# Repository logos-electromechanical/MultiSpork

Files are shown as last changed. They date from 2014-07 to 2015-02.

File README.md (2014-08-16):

MultiSpork
==========

A wireless analog/digital multitool &amp; data recorder.

When I'm working on a mobile robotics projects, I often wish I could attach my scope, logic analyzer, or signal generator to some aspect of the 'bot without tethering it to the bench. IOW, what I need is some kind of widget that does the data acquisition on the 'bot and sends it back to a screen. Ideally, it would also have plenty of range, easy configuration, a nice interface (Saleae is my model for how this should be). 

Maxim just released a chip, the MAX 11300, that incorporates a good chunk of what's required for this. It gives you twenty channels, each of which can by ADC, DAC, or GPIO, and communicates over a fast SPI bus. Add an Atmel SAM processor (I already have the dev tools, so this is an easy decision) and a wifi module, and we're in business. Cheap wifi-only Android tablets can be had for as little as $50, so Android is the obvious choice for a host OS. 

See the MultiSpork/documentation/MultiSporkSystemDescription.md for more info. This will go into the wiki when it's complete.

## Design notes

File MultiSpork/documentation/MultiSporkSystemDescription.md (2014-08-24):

MultiSpork -- A Wireless Analog/Digital Multitool
=================================================================

# Concept #

The MultiSpork is an analog and digital multitool. It has the following properties:

* It has twenty channels can function as a 12-bit ADC, a 12-bit 25 mA DAC, or a GPIO line. 
* Interfaces wirelessly with a tablet or other display device for user input and data presentation. 
* Robust
* Able to store data locally on an SD card
* Able to operate without continuous network connection
* Initial set-up is easy/straightforward
* Both firmware and app incorporate plug-in frameworks to allow easy 3rd party upgrades.
* Replicates behavior of a mixed-signal oscilloscope
* Replicates behavior of a logic analyzer
* Replicates behavior of a signal generator

Features listed as (OPTIONAL) are ones that I haven't decided I'm definitely going to implement immediately, but that would be nice in the future. 

----------

# Hardware #

## General Hardware Requirements ##
The hardware must conform to the following requirements:

* It must be electrically robust against common insults, especially over-voltage, over-current conditions, and the sort of ESD likely to be encountered in field conditions.
* It must be robust against plugging connectors in backwards. Therefore, all connectors must be either keyed, tolerant of connector reversal, or both. 
* The hardware must be amenable to expansion
* It must be mechanically robust, particularly the connectors. 

## Subsystems ##

### Analog Front End/Digitizer ###

The ADC/DAC/GPIO services are provided by the MAX11300. This chip provides twenty lines, each of which may be individually programmed to act as an ADC, a DAC, or a GPIO. All ADC and DAC channels are 12-bit, and share a total of 400 ksps. 

Voltage ranges are as follows:

|**Function** 	| **Voltage Range** |
|---|---|
|ADC			| 	0-10V			|
|				|	-5V to 5V		|
|				|	-10V-0			|
|				|	0-2.5V			|
|---------------|-------------------|
|DAC			| 	0-10V			|
|				|	-5V to 5V		|
|				|	-10V-0			|
|---------------|-------------------|
|GPI			|	0-5V input		|
|				|	0-2.5V threshold|
|				|	(programmable)	|
|---------------|-------------------|
|GPO			|	0-10V (programmable)|
|---------------|-------------------|

#### Voltage Reference ####

Only the internal voltage reference(s) are available.

#### Temperature ####

Both external temperature sensors lines are hooked up to MMBT3904 transistors. This circuit is cribbed directly from the MAX11300 evaluation board. 

#### Host Interface ####

The SPI lines are hooked directly to the MCU, as are the CNVT and INT lines.

#### I/O Protection Circuit ####

Each of the channels has the following circuit:

The series diodes restrict the voltage at MAX11300 input pin to between -10V and +10V. The PTC fuse limits the current to 25 mA in order to prevent damage. 

#### I/O Connector ####

The analog I/O connector is an FCI 76385-316LF soldered to the edge of the board. This is a 2x16 0.1" pitch pin header. This reduces the height of the assembled board and increases mechanical strength. While this is a keyed connector, it can accept non-keyed IDC plugs. Therefore, the pinout is symmetrical, so that reversing the connector will not connect any power or ground rail to any I/O line or to any other power or ground rail.

Pinout is as follows:

| **Pin** 	| **Function** 		|
|---|---|
| 1			| Analog Ground		|
| 2			| +3V3				|
| 3			| Digital Ground	|
| 4			| +5V				|
| 5			| -10V				|
| 6			| +10V				|
| 7			| PORT 00			|
| 8			| PORT 01			|
| 9			| PORT 02			|
| 10		| PORT 03			|
| 11		| PORT 04			|
| 12		| PORT 05			|
| 13		| PORT 06			|
| 14		| PORT 07			|
| 15		| PORT 08			|
| 16		| PORT 09			|
| 17		| PORT 10			|
| 18		| PORT 11			|
| 19		| PORT 12			|
| 20		| PORT 13			|
| 21		| PORT 14			|
| 22		| PORT 15			|
| 23		| PORT 16			|
| 24		| PORT 17			|
| 25		| PORT 18			|
| 26		| PORT 19			|
| 27		| +10V				|
| 28		| -10V				|
| 29		| +5V				|
| 30		| Digital Ground	|
| 31		| +3V3				|
| 32		| Analog Ground		|

### MCU ###

The microcontroller is an Atmel SAM3S4A. This chip comes in a QFN 48 package and sports 256K of flash and 48K of SRAM. Clock speed is 64 MHz and maximum SPI speed is 45 MHz. 

Programming is accomplished either via USB or the JTAG interface. 

A 20 MHz crystal regulates the on-chip crystal oscillator

Microcontroller circuitry follows the datasheet to the extent required & practical.

The SPI bus provides the only means of communication between the major subsystems.

The MCU will have at least 1 MByte of external SRAM in order to support a sufficiently deep buffer to tolerate excessive waits from the SD Card.

#### Accessory connector ####

The accessory connector exposes the serial communication interfaces of the MCU in order to provide a place for adding additional hardware. It is a 2x5 0.1" pitch pin header. It is not populated by default. 

Pinout is as follows:

| **Pin** 	| **Function** 		|
|---|---|
| 1			| MOSI (SPI Bus)	|
| 2			| +3V3				|
| 3			| SCLK (SPI Bus)	|
| 4			| RXD0 (UART0)		|
| 5			| MISO (SPI Bus)	|
| 6			| TXD0 (UART0)		|
| 7			| ACC_CS (SPI Bus)	|
| 8			| SCL (I2C Bus)		|
| 9			| SDA (I2C Bus)		|
| 10		| Digital Ground	|

### WiFi ###

Wireless communication is provided by a Texas Instruments CC3100. This 2.4 GHz WiFi SoC provides all network services required for the MultiSpork to communicate with its host tablet. 

The CC3100 is configured to act as an access point. This eliminates the need for the user to execute any wired configuration step prior to using the MultiSpork. Access point configuration options will naturally be available from the tablet app. 

CC3100 wiring follows the dictates of the datasheet. 

### USB ###

USB is a native peripheral of the microcontroller. The USB port is protected against ESD and electrical insults by series resistors.

USB power is used to charge the battery.

### SD Card ###

A micro-SD card slot provides non-volatile data storage when the Multispork is directed to log incoming data. It also provides storage for outgoing waveforms and (possibly) scripts to run. 

### Idiot Lights ###

The MultiSpork shall have the following idiot lights. Features listed in *italics* have not yet been implemented as of commit 872e8fda3353304001933b7b57375441d28ed381.

* Charge, red LED
* *Power, green LED*
* *State, RGB LED*

### Power ###

#### Switch ####

The power switch controls the enable lines of all of the voltage regulators. In the off position, it puts them all to sleep.  

#### Battery ####

Main power for the device is provided by a single LiPo cell (2.7-4.2V) with a 2mm JST connector. This battery is intended to be permanently installed, but can be removed and upgraded if required for a specific application.

The battery is charged by an MCP73831 linear charge controller set to 500 mA of charge current. 

#### 3.3V Rail ####

The 3.3V rail powers the MCU, the WiFi chip, and the digital interface of the MAX11300. It therefore has the highest power demand of any of the power rails.

This rail is driven by an LT3580 regulator configured to run in SEPIC mode. The components are sized to provide a current output of 800 mA.  

#### 5V Rail ####

The 5V rail powers the core of the MAX11300. Like the 3.3V rail, it is driven by an LT3580 regulator running in SEPIC mode. The current output is 400 mA. 

#### +10V Rail ####

The +10V provides the high voltage positive rail for the MAX11300. It is driven an LT3580 configured as a boost regulator. Current output is 350 mA. 

#### -10V Rail ####

The -10V provides the high voltage negative rail for the MAX11300. It is driven by an LT3580 configured as an inverting regulator. Current output is 350 mA. 

#### Analog Ground ####

The analog ground plane is connected to the digital ground plane through a small resistor. 

## Mechanical ##

### PCB ###

The production version of the MultiSpork will fit within a Dangerous Prototype DP8049 Sick of Beige footprint. 

The PCB will be a four-layer design, 0.062" finished thickness. 

### Case ###

The case will be a milled Delrin case with an acrylic lid. It will have space for a battery and associated retention features. The case shall also provide a mechanism to operate the reset button and the power switch. It shall also provide visibility for the charge and power LEDs. 

## Future Hardware Features ##

This is a list of things that I have thought of that would be nice to have but are probably not worth the candle, at least at the time.

* GPS for accurate time and location tagging (see, for example, the SE4150L -- $3/ea in singles). This is significantly more interesting than just an RTC.
* External RAM for larger on-board buffer

----------

# Firmware #

The firmware configures the MAX11300, and exchanges data with the MAX11300, the WiFi, and the SD card. It has the following functions:

* Acquire data from the ADC and GPI at full speed (400 ksps)
* Pipe data to the DAC and GPO at full speed
* Provide access to all major MAX11300 and CC3100 configuration options
* Log data to SD card
* Read arbitrary waveforms from SD card
* Transmit data over WiFi to tablet
* Generate standard analog waveforms (sine, square, triangle, white noise, etc)
* Generate standard digital waveforms (PWM, PCM, etc)
* Capture data from ADC/GPI based on trigger conditions (level and edge triggers)
* Transmit data over DAC/GPO based on trigger conditions
* (OPTIONAL) Apply arbitrary polynomial transfer functions to incoming data
* (OPTIONAL) Apply mathematical functions (add, subtract, multiply, trig) to incoming data
* (OPTIONAL) Pipe filtered data to arbitrary DAC channel
* (OPTIONAL) Read configuration options from SD Card
* (OPTIONAL) Read and write data from accessories on the SPI and I2C busses
* (OPTIONAL) Run arbitrary LUA scripts on incoming/outgoing data

## Configuration ##

The general intention is that the configuration options in the firmware are thin wrappers around the MAX11300 and CC3100 configuration registers. 

## Data Flow ##

The major system blocks are as follows:

* **MAX11300** -- Primary physical interface, both in and out
* **MCU SPI** -- The communications bus with all peripherals save the USB
* **MCU buffers** -- Internal RAM buffers used for input and output 
* **MCU filters** -- Internal filter programs
* **MCU signal generator** -- Algorithmic signal generation
* **SD Card** -- Local SD card for storing data
* **CC3100** -- WiFi connection to host app
* **USB** -- USB connection to host app
* **Host App** -- Host application running on a tablet or other computer

### MAX11300 ###

The MAX11300 block communicates via the MCU SPI block. It takes in commands, configuration, and output data. It puts out input data from its analog and digital inputs. 

### MCU SPI ###

The SPI is the communications bus that connects the MAC11300, the MCU (and all its internal blocks), the SD card, and the CC3100. It may carry any of the data types that these blocks transmit or receive. 

### MCU buffers ###

The MCU buffers incoming and outgoing data from and to the MAX11300 that is either going to or received from other blocks over the SPI. Each active channel has its own buffer, which will be either read or write depending on what function is currently configured on that channel. The WiFi, the USB, and the SD card each have a read and a write buffer.

### MCU filters ###

The MCU can run filters (decimation, low pass, various multi-input math functions etc) against data that is in any buffer. The output is written to another buffer. 

### MCU signal generator ###

The signal generator fills an output buffer with a specified function. Here is a list of functions to be implemented in the first iteration:

* sine wave
* square wave
* triangle wave
* sawtooth wave
* PWM

### SD Card ###

The SD card is a data store that the MCU can either write to or read from via SPI bus.

Output data files will be stored as plain text CSV files in the format <channel>,<time>,<value>,<units>. In the case of raw values, the value of the <units> field shall be 'raw'. Any other value shall be set by the translating filter.

Input data files shall be in .wav format. The name and details of the .wav file are set by the 

### CC3100 ###

The CC3100 provides the WiFi link to the host app. It sends and receives data and commands from the MCU via SPI and communicates with the host app via WiFi. 

### USB ###

The USB performs the same functions as the WiFi when the USB is connected to a host. 

### Host App ###

The host app is the ultimate data sink and source in the system. It provides the following types of data to the device:

* Commands (i.e. state changes, state details)
* Configuration (i.e. trigger settings, channel settings)
* .wav files for data output
* (OPTIONAL) Commands, config, and outgoing data for things attached to the accessory connector.

The host app receives the following types of data from the device:

* Streaming input data from the MAX11300
* Status from various parts of the device

## States ##

### Setup ###

This is the state that the MultiSpork enters upon power-up or reset. In this state, it performs the following tasks before transitioning to either Standby or Logging mode (depending on configuration).

1. Configures CC3100 per one of the following profiles (listed in priority order):
	1. (OPTIONAL) WiFiConf.txt, stored on the SD Card
	2. The wifi configuration stored in the EEPROM of the MCU
	3. The default wifi configuration  
2. Configure the MAX11300 per one of the following configurations (listed in priority order):
	1. (OPTIONAL) IOConf.txt, stored on the SD Card
	2. The I/O configuration stored in the EEPROM of the MCU
	3. The default I/O configuration  
4. Chooses mode to enter based on either EEPROM or (OPTIONAL)SD Card configuration.
5. Gets current data/time from host device.

### Standby ###

This is the default waiting state. The primary activity in this state is executing configuration commands from the host app. The device will depart this state for pre-trigger, running capture, or logging based on input from either the host app or from a command file on the SD card. 

The MCU can generate or output a signal through the MAX11300 in this mode and any other except Setup. 

### Pre-Trigger ###

During the pre-trigger state, the MCU commands the MAX11300 to sample the target channel(s) and saves the buffer such that when the trigger condition occurs, the app can display data from both before and after the trigger condition. 

Trigger conditions can come from any of the following sources:

* Analog input
* Digital input
* Analog output
* Digital output
* Internal timebase

Any of the following conditions can be used to trigger a capture

* Level trigger
* Edge trigger
* Periodic trigger
* Free run

Once the trigger condition is satisfied, the firmware transitions to the next state (either Triggered Capture, Running Capture, or Logging) as dictated by the received commands. 

### Triggered Capture ###

During a triggered capture, the device captures and streams data until it reaches the end of the specified capture window. It then either returns to the pre-trigger state or to standby, depending on whether the triggering is set to be continuous or one-shot.

### Running Capture ###

During a running capture, the device captures and streams data to the host app continuously, either via USB or WiFi. Starting and stopping 

### Logging ###

Logging works like a running capture except that the target is the SD card rather than USB or WiFi. Depending on settings, the MCU filters may decimate or otherwise process the incoming data before writing it out. 

It shall be possible to configure this state such that the logging proceeds for a limited time period and then transitions back to pre-triggered or standby. 

----------

# Host App

The host app will be designed to present the acquired data in a format that can be readily viewed and manipulated by the user. 

The host app shall be written in Kivy or similar cross-platform framework that allows them to run on not only Android tablets but also on Windows, Linux, and Mac. 

The host app interface will follow the wireframes at https://logoselectromechanical.mybalsamiq.com/projects/multispork/

----------

# Communications

The maximum data rate from the MAX11300 is 4.8 Mbps. This provides plenty of SPI bus headroom to stream to the host app and record simultaneously, since its maximum speed is 20 Mbps, as long as there's a minimal amount of framing data. This means that the outgoing data needs to be packed up such that a single set of framing data covers a substantial period of communications.

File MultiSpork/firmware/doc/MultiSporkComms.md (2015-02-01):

# Communications #

## Hardware Components ##

### Host ###

The host is the user interface device. Typically, this will be an app running on an Android tablet, but it may be any computer running the appropriate software. 

Typically, all transactions with the exception of raising interrupts are initiated by the host. 

### Device ###

The device is the operational head of the system. The Multispork is the only device at this time. 

# Transactions #

Each transaction starts with the initiating party (always the host except for raising interrupts) send a request. The other party then sends one or more messages in response. 

Communications is serialized with the [Cap'n Proto](https://capnproto.org/) package. All message descriptions use the terminology of that package. 

## Parameters ##

Parameters are the configuration values used to tell the device how to operate. The value and identity of each parameter are defined with the type `ParamStruct`.

### Messages ###

#### `ParamStruct` ####

This structure contains all the information required for a particular parameter.

- `name` This is the text name of the parameter. This is not necessarily a unique value and exists mostly for readability.
- `guid` This is a 64-bit globally unique ID number. It must not overlap with other guids for other message types. A single guid may exist for multiple channels. 
- `channel` This is the channel to which this particular value applies. A single guid may cover multiple channels. If the parameter covers all channels, this value should be 255.
- `value` This is the value of the parameter. Any unitary type from Cap'n Proto can be used here. `Void` is used signal a request.

#### `ParamErr` ####

This is an enumerated type that is used to transmit an error if a parameter transaction fails for some reason. The values it can assume are as follows:

- `none` No error
- `invalidParamName` Invalid parameter name. Returned if the guid does not match the name.
- `invalidParamGUID` Invalid guid. Returned if the guid does not exist.
- `invalidParamValue` Invalid parameter value. Returned if the parameter is out of range. 
- `invalidParamChannel` Invalid parameter channel. Returned if the parameter has an incorrect channel.
- `accessDenied` Not currently used
- `paramSetFail` Parameter set failed. Returned if the device is unable to set the parameter value for a reason no previously listed. 
- `invalidParamType` Invalid parameter type. Returned if the parameter type sent to the device does not match the internal type. 

### Getting a Parameter ###

In order to get the current value of a given parameter, the host sends a `ParamStruct` with the name, UID, and channel of the desired parameter value of `request`, which is of type `Void`. 

The device responds either with the requested `ParamStruct` and a `ParamErr`. `ParamErr` is an enumerated type containing a variety of possible error types.

If the parameter exists, the device sends the host a `ParamStruct` for that parameter including the value.

If the parameter does not exist, the device responds with a `ParamErr` with an appropriate value. 

### Setting a Parameter ###

In order to set a parameter, the host sends the device a `ParamStruct`. The device responds with a `ParamErr`.

### Getting a List of Parameters ###

In order to get a list of parameter, the host sends a `List(ParamStruct)` containing a single empty parameter. The device responds with a `List(ParamStruct)` containing all device parameters. 

## Interrupts ##

The device sometimes needs to interrupt the host, for example, when a buffer is full and ready for reading.

Upon receiving an interrupt, the host takes whatever actions are necessary to deal with the interrupts, and then sends the `IntStruct` back to clear the interrupt. 

### Messages 

#### `IntStruct` ####

- `name` The natural language name of the interrupt.
- `guid` The globally unique 64 bit ID of the interrupt.
- `channel` The channel to which the interrupt applies. An interrupt that applies to all channels or no channel in particular fills this with the value 255.

## Buffers ##

Buffers are where the data being read into the device (via GPI or ADC) or out of the device (via GPO or DAC) are stored. Typically, buffers come in pairs so one or the other can be manipulated by the host while the other is being read from or written to by the device. 

### Messages 

#### `BufStruct`

- `ID` is a `BufID` struct containing all of the data about the buffer's identity. Its members are as follows:
	- `channels` contains a list of channel numbers addressed by this buffer. It is a `List(UInt8)`.
	- `bufNum` is the buffer number, which makes it straightforward to keep track of different buffers for the same channel list. It is a `UInt8`.
	- `rate` is the sample rate of the buffer. It is a `Float32`.
	- `startTime` is the start time of the buffer. It is a `UInt64`.
	- `size` is the size of the buffer, in samples. It is a `UInt32`. The size of the buffer in bits is equal to `size` times `resolution`.
	- `contentSize` is the number of samples currently in the buffer.
	- `resolution` is the size of each sample, in bits. It is a `UInt8`, and for the MultiSpork will be either equal to 12 (for an ADC or DAC buffer) or 1 (for a GPIO buffer).
	- `direction` is the direction that the buffer will be written. It is a `Bool` and is true for an input buffer and false for an output buffer.
	- `active` is a `Bool` that is true if the buffer is being actively read to or written from by the device and is false otherwise. 
- `contents` is a `Data` blob containing the contents of the buffer. The samples are packed together with no padding, and contains the samples from each channel called out in the channel list in a maximum density packing.

#### `BufErr` ####

This is an enumerated type with all the possible buffer errors.

- `none` No error
- `bufDoesNotExist` There is no buffer with the given channel list.
- `bufEmpty` There are no samples in the buffer. 
- `bufOverflow` Either `contentSize` is larger than `

### Getting a Buffer ###

In order to get a buffer, the host sends a `BufStruct` that is empty except for the `channels` and the `bufNum`. If that channel list corresponds to a buffer on the device, the device responds with a fully populated `BufStruct`. Otherwise, it will return a `BufErr` with an appropriate value.

### Writing a Buffer ###

In order to write a buffer, the host sends a fully populated `BufStruct`. If that buffer corresponds to a buffer on the device, the device responds with a `BufErr` with the value `none`. Otherwise, it will return an appropriate error.

### Getting a List of Buffers ###

To get a list of all valid buffers, the host transmits a `List(BufID)` containing a single empty instance of `BufID`. The device responds with a `List(BufID)` containing all buffers currently in use. 

# Multispork Configuration #

This is a list specifically of the configuration of the MultiSpork. Other devices will likely have different parameters.

## Parameters ##

### Network ###

**Name** | **GUID** | **Type** | **Permitted Values** | **Default** | **Function** | 
---------|----------|----------|----------------------|-------------|--------------|
Device Name | | String | Any string that is permissible as an internet host name | multispork\<serial number\> | This is a name to allow the user to identify different devices from a single host. This is also the network SSID in host mode |
Device IP Address | | UInt32 | Any valid IP address | 10.10.10.10 | This is the IP address of the device. In client mode, this will be populated via DHCP; otherwise, it is populated from the last value stored in NVM |
WPA2 Key | | String | Any string | none | This is the password used for logging in to the device by the host. If the device is not in host mode, it will use this password to log in to the target network. |
Target SSID | | String | Any valid SSID | none | This is the network the device attempts to log in to in client mode |
Host Mode | | Bool | | true | When true, the device functions as a WiFi access point. Otherwise, it attempts to log in to the network stored in Target SSID |

### Global I/O Configuration ###

These are the parameters that control all channels of a given type.

**Name** | **GUID** | **Type** |**Channels Affected** | **Permitted Values** | **Default** |  **Function** |  
---------|----------|----------|----------------------|----------------------|-------------|---------------|
Sample Averaging | | UInt8 | All ADC | 1, 2, 4, 8, 16, 32, 64, or 128 | 1 | Set the number of samples averaged for each analog input sample transmitted to the host. |
ADC rate | | UInt16 | All ADC | 200, 250, 333, or 400 | 200 | The base sampling rate in ksps. The delivered sampling rate is `ADC rate`/`Sample Averaging`. |

### Channel Configuration ###

Analog input channels may be 0-22, where 0-19 are the ADC channels, 20 is the internal temperature sensors, 21 and 22 are the external temperature sensors. Analog output and all GPIO channels may be 0-19.

**Name** | **GUID** | **Type** | **Channels** | **Permitted Values** | **Default** |  **Function** |  
---------|----------|----------|--------------|----------------------|-------------|---------------|
Channel Mode | | UInt8 | Any | 0-6, where 0 = off, 1 = single ended ADC, 2 = pseudo-differential ADC, 3 = differential ADC, 4 = DAC, 5 = GPI, 6 = GPO | 0 | Set the mode for the given channel |
Voltage Range || UInt 8 | Any | 0-7 | 0 | See voltage range table in MAX11300 datasheet for FUNCPRM_i[11:0] |
Digital Threshold | | UInt16 | Any channel currently in GPIO mode | 0-4095 | 4095 | Sets the threshold voltage for digital input with respect to the DAC threshhold described by the Voltage Range Parameter. In digital output mode, output voltage is 4x the digital input level |
Negative Differential Channel | | UInt8 | 0-19 | 0 | This is the negative side for the channel while in differential or pseudod-differential mode. The target channel must be turned off. |
Pseudo Differential Voltage | | UInt16 | Any channel currently targetted as the negative input of a pseudo-differential channel | 0-4095 | 0 | This is the negative terminal of a pseudo-differential channel. |
DAC Running | | Bool | Any channel configured as a DAC output | | false | When this is false, the value of the DAC channel will be equal to DAC voltage, given the value of Voltage Range. |
DAC Voltage | | UInt16 | Any channel configured as a DAC output and with DAC Running = false | 0-4095 | 0 | The voltage output of the given channel. |

### Trigger ###

**Name** | **GUID** | **Type** | **Permitted Values** | **Default** | **Function** | 
---------|----------|----------|----------------------|-------------|--------------|
Trigger Channel | | UInt8 | 0-19 | 0 (no trigger) | Defines which channel will be used as a trigger.|
Trigger Sweep | | UInt8 | 0-2 | 0 (auto) | Defines whether the triggering is auto (0), normal (1), or single (2). |
Trigger Armed | | Bool | | false | When the Trigger Sweep is in single sweep mode, the host sets this true to enable the next sweep |
Trigger Level | | Float32 | -10 to +10 | 0 | Trigger level in volts |
Trigger Type | | UInt8 | 0-2 | 0 | 0 = edge trigger, 1 = pulse trigger, 2 = slope trigger |
Trigger Slope | | UInt8 | 0-2 | 0 | 0 = rising, 1 = falling, 2 = either |

## Interrupts ##

**Name** | **GUID** | **Channel** | **Function** |
---------|----------|-------------|--------------|
Buffer Full | | The lowest channel number in the buffer just filled | Tells the host when the device has filled a buffer |
Trigger Tripped | | The channel of the trigger | Tells the host when the a trigger condition has fired |

## Buffers ##

The Multispork allocates a maximum of eight buffers -- two analog input buffers, two analog output buffers, two digital input buffers, and two digital output buffers. They are allocated dynamically in response to the configuration of the channels.

**Description** | **Buffer Num**  | **Channels** | **Function** |
----------------|-----------------|--------------|--------------|
Analog Input Buffer | 0 | All channels that are configured as analog inputs | Stores samples as they are read in via ADC |
Analog Input Buffer | 1 | All channels that are configured as analog inputs | Stores samples as they are read in via ADC | 
Analog Output Buffer | 0 | All channels that are configured as analog outputs and have the DAC Running parameter set to true. | Stores samples to be written out via DAC |
Analog Output Buffer | 1 | All channels that are configured as analog outputs and have the DAC Running parameter set to true. | Stores samples to be written out via DAC |
Digital Input Buffer | 0 | All channels that are configured as digital inputs | Stores digital inputs as they are read in |
Digital Input Buffer | 1 | All channels that are configured as digital inputs | Stores digital inputs as they are read in |
Digital Output Buffer | 0 | All channels that are configured as digital outputs | Stores digital outputs to be written out |
Digital Output Buffer | 1 | All channels that are configured as digital outputs | Stores digital outputs to be written out |

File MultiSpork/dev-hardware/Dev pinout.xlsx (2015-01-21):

 | MAX11300 |  | CC3100BOOST |  | Olimex
Connection | Pin | Function | Pin | Function | Pin | Function
1 | 6,12 | 3V3 | P1.1 | 3V3 | 3.3V
2 | 5,11 | GND | P2.1 | GND | GND
 |  |  | P3.2 | GND
3 |  |  | P3.1 | 5V | +5V_USB
4 | 4 | SCLK | P1.7 | SPI_CLK | PA14 | SPCK
5 | 3 | MISO | P2.7 | SPI_MISO | PA12 | MISO
6 | 2 | MOSI | P2.6 | SPI_MOSI | PA13 | MOSI
7 | 1 | CS |  |  | PB0 | GPIO
8 | 7 | INTB |  |  | PB2 | GPIO
9 | 10 | CNVTB |  |  | PB3 | GPIO
10 |  |  | P2.2 | IRQ | PA5 | GPIO
11 |  |  | P2.3 | SPI_CS | PA6 | GPIO
12 |  |  | P1.5 | nHIB | PA0 | GPIO
13 |  |  | P2.5 | nRESET | PA9 | GPIO
14 |  |  | P4.7 | NWP_LOG_TX | PA1 | GPIO
15 |  |  | P4.8 | WLAN_LOG_TX | PA3 | GPIO

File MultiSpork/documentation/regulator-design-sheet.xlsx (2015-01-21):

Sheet: +10V regulator (LT3580)
Part | LT3580
Vout | 10 | V | Output voltage
Iout(max) | 0.35 | A | Maximum current
Vin(bat) | 2.5 | V | Minimum battery voltage, after diode
Vin(USB) | 5 | V | USB bus voltage
Rfb | 105.4621849 | kΩ
DCbat | 0.79 |  | Duty cycle on minimum battery power
DCUSB | 0.55 |  | Duty cycle on USB power
fOSC | 1.914583333 | MHz
RT | 47.00 | kΩ
Tp | 522.31 | ns | Clock period, ns
DCmax | 0.89 |  | Max allowable duty cycle
Lmin(bat) | 0.64 | µH
Lmin(USB) | 0.45 | µH
Lmin(bat) | 3.56 | µH | Value to prevent subharmonics
Lmin(USB) | 0.56 | µH | Value to prevent subharmonics
Lmax(USB) | 14.16 | µH
Lmax(bat) | 9.54 | µH
Lfinal | 3.90 | µH | Selected value
IL-peak | 1.72 | A
Cin | 4.7 | µF
Cout | 20 | µF
Cseries | 2.20 | nF | Note that these are taken from the SEPIC converter in datasheet rather than calculated. They'll be done properly later.
Cparallel | 0.00 | pF
Rseries | 10.00 | kΩ
L p/n | SRR5018-3R9Y
L package | 2323 (5858 metric)

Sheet: 3.3V SEPIC regulator
Part | LT3580
Vout | 3.2 | V | Output voltage
Vd | 0.7 | V | Diode voltage drop
Iout(max) | 0.8 | A | Maximum current
Vin(bat) | 2.5 | V | Minimum battery voltage, after diode
Vin(USB) | 5 | V | USB bus voltage
Rfb | 23.82953181 | kΩ
DCbat | 0.64 |  | Duty cycle on minimum battery power
DCUSB | 0.45 |  | Duty cycle on USB power
fOSC | 1.914583333 | MHz
RT | 47.00 | kΩ
Tp | 522.31 | ns | Clock period, ns
DCmax | 0.89 |  | Max allowable duty cycle
Lmin(bat) | 1.78 | µH
Lmin(USB) | 0.91 | µH
Lmin(bat) | 1.01 | µH | Value to prevent subharmonics
Lmin(USB) | -0.44 | µH | Value to prevent subharmonics
Lmax(USB) | 11.72 | µH
Lmax(bat) | 7.73 | µH
L1 | 2.20 | µH | Selected value
L2 | 2.20 | µH | Selected value
IL1-peak(bat) | 1.56 | A
IL2-peak(bat) | 0.94 | A
IL1-peak(USB) | 1.63 | A
IL2-peak(USB) | 1.01 | A
Cin | 4.7 | µF
Cout | 20 | µF
Cseries | 1.00 | nF | Note that these are taken from the SEPIC converter in datasheet rather than calculated. They'll be done properly later.
Cparallel | 22.00 | pF
Rseries | 10.00 | kΩ
L1 p/n | 252012CDMCDS-2R2MC
L1 package | 1008 (2520 metric)
L2 p/n | 252012CDMCDS-2R2MC
L2 package | 1008 (2520 metric)

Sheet: +5V SEPIC regulator
Part | LT3580
Vout | 4.95 | V | Output voltage
Vd | 0.7 | V | Diode voltage drop
Iout(max) | 0.4 | A | Maximum current
Vin(bat) | 2.5 | V | Minimum battery voltage, after diode
Vin(USB) | 5 | V | USB bus voltage
Rfb | 44.8 | kΩ
DCbat | 0.72 |  | Duty cycle on minimum battery power
DCUSB | 0.55 |  | Duty cycle on USB power
fOSC | 1.914583333 | MHz
RT | 47.00 | kΩ
Tp | 522.31 | ns | Clock period, ns
DCmax | 0.89 |  | Max allowable duty cycle
Lmin(bat) | 0.50 | µH
Lmin(USB) | 0.64 | µH
Lmin(bat) | 2.05 | µH | Value to prevent subharmonics
Lmin(USB) | 0.53 | µH | Value to prevent subharmonics
Lmax(USB) | 14.11 | µH
Lmax(bat) | 8.71 | µH
L1 | 2.20 | µH | Selected value
L2 | 2.20 | µH | Selected value
IL1-peak(bat) | 1.27 | A
IL2-peak(bat) | 0.56 | A
IL1-peak(USB) | 1.38 | A
IL2-peak(USB) | 0.67 | A
Cin | 4.7 | µF
Cout | 20 | µF
Cseries | 1.00 | nF | Note that these are taken from the SEPIC converter in datasheet rather than calculated. They'll be done properly later.
Cparallel | 22.00 | pF
Rseries | 10.00 | kΩ
L1 p/n | 252012CDMCDS-2R2MC
L1 package | 1008 (2520 metric)
L2 p/n | 252012CDMCDS-2R2MC
L2 package | 1008 (2520 metric)

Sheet: -10V regulator
Part | LT3580
|Vout| | 10 | V | Output voltage
Iout(max) | 0.35 | A | Maximum current
Vin(bat) | 2.5 | V | Minimum battery voltage, after diode
Rfb | 120.1080432 | kΩ
DCbat | 0.83 |  | Duty cycle on minimum battery power
fOSC | 1.914583333 | MHz
RT | 47.00 | kΩ
Tp | 522.31 | ns | Clock period, ns
DCmax | 0.89 |  | Max allowable duty cycle
Lmin(bat) | 2.95 | µH
Lmin(bat) | 5.05 | µH | Value to prevent subharmonics
Lmax(bat) | 10.03 | µH
L1-final | 5.30 | µH | Selected value
L2-final | 5.60 | µH
IL1-peak | 1.97 | A
IL2-peak | 0.43 | A
Cin | 4.7 | µF
Cout | 20 | µF
Cseries | 2.20 | nF | Note that these are taken from the SEPIC converter in datasheet rather than calculated. They'll be done properly later.
Cparallel | NP | pF
Rseries | 10.00 | kΩ
L1 p/n | SRR5028-5R3Y
L1 package | 2323 (5858 metric)
L2 p/n | PM1008S-5R6M-RC
L2 package | 1008 (2520 metric)

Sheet: +10V regulator
Part | AD1614
Vout | 10 | V | Output voltage
Iout(max) | 0.35 | A | Maximum current
Vin(bat) | 2.5 | V | Minimum battery voltage, after diode
Vin(USB) | 5 | V | USB bus voltage
R1fb | 70.32128514 | kΩ
R2fb | 10 | kΩ
DCbat | 0.75 |  | Duty cycle on minimum battery power
DCUSB | 0.50 |  | Duty cycle on USB power
fOSC | 1.3 | MHz
Ton(bat) | 0.58 | µs
Ton(USB) | 0.38 | µs
Iripple(max) | 0.40 | A
Lmin(bat) | 3.61 | µH
Lmin(USB) | 4.81 | µH
Lfinal | 4.70 | µH | Selected value
IL-peak | 1.60 | A
Cin | 22 | µF
Cout | 22 | µF
Cseries | 1.00 | nF | Note that these are taken from the SEPIC converter in datasheet rather than calculated. They'll be done properly later.
Cparallel | 22.00 | pF
Rseries | 10.00 | kΩ

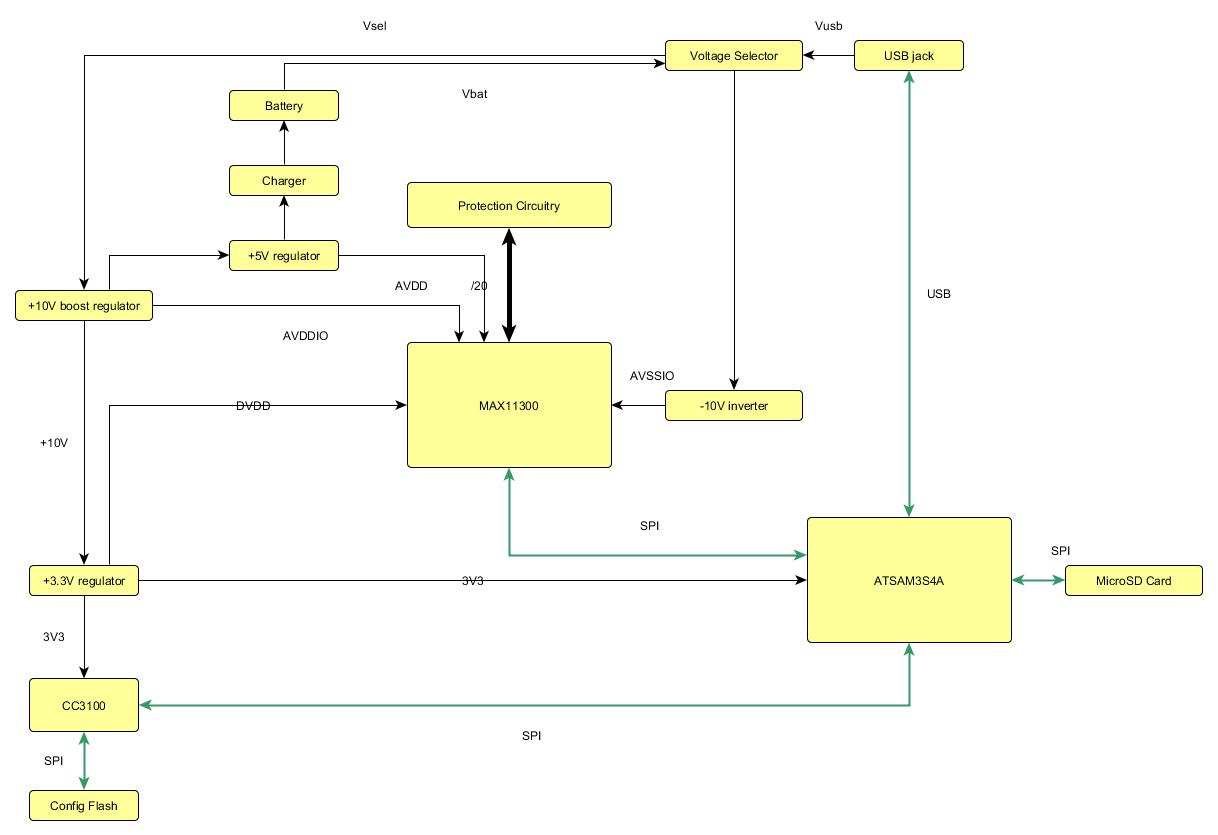
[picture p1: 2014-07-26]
MultiSpork/documentation/Hardware-block-diagram.jpg

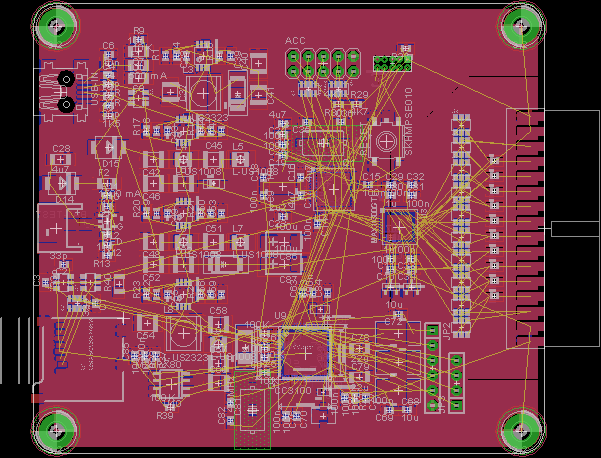
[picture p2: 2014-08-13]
MultiSpork/documentation/Multispork-placement-web.png

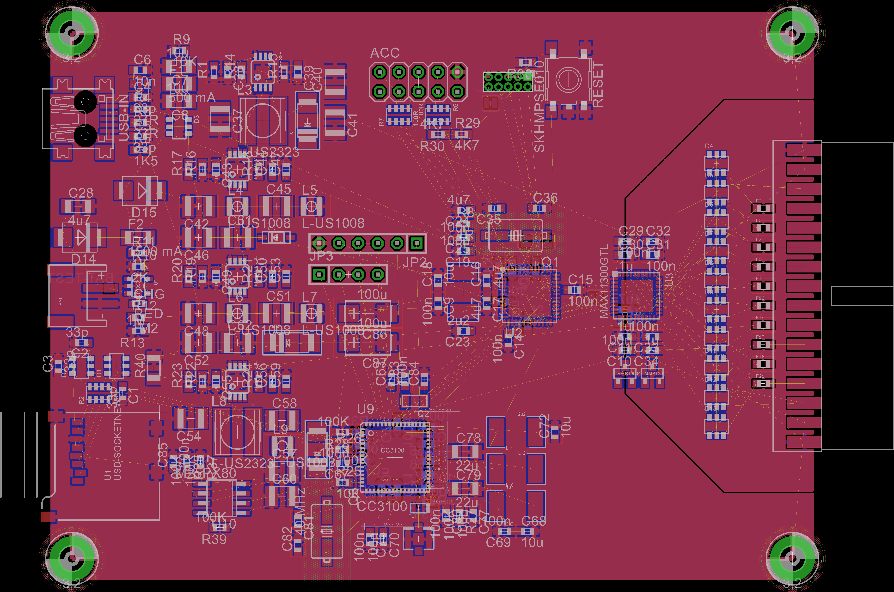
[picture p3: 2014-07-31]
MultiSpork/documentation/Multispork-placement.png

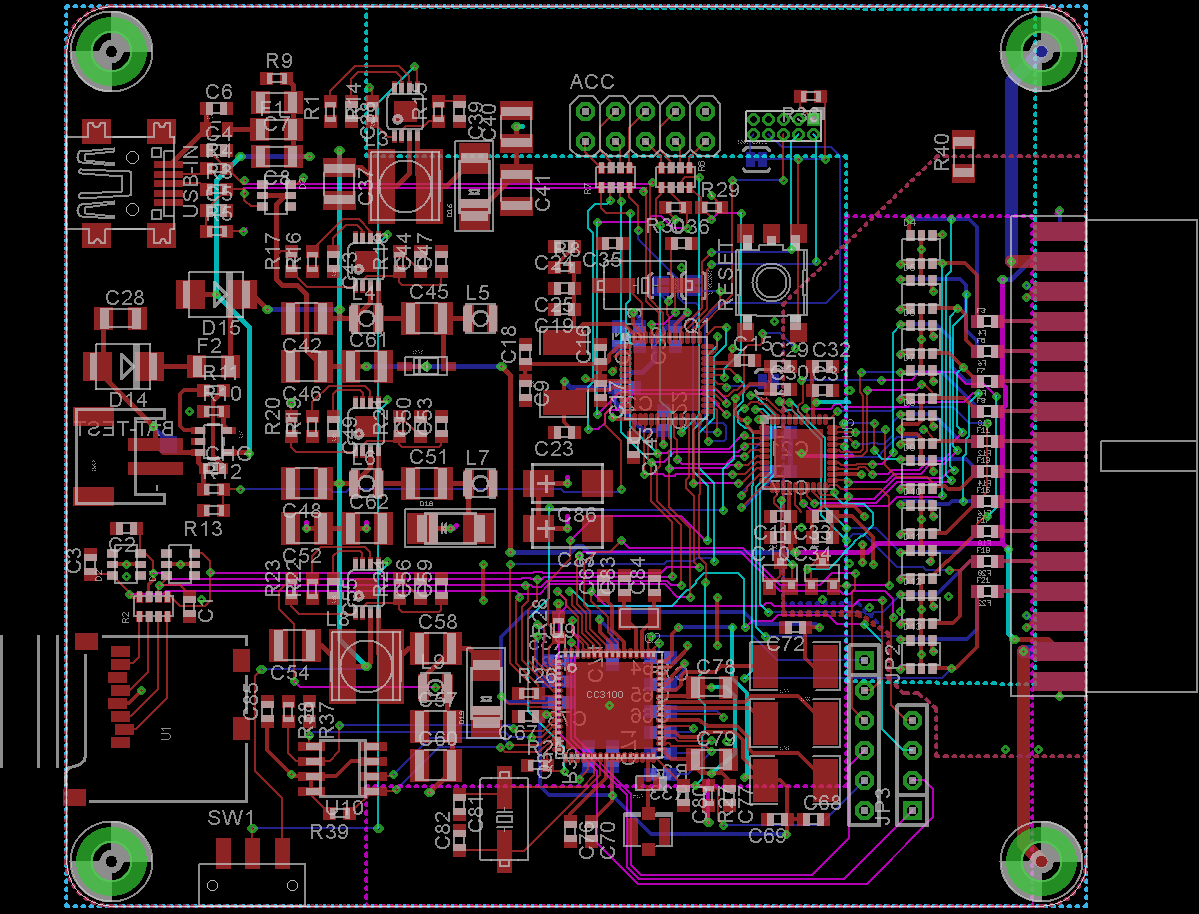
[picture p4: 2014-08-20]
MultiSpork/documentation/MultiSpork-v1-routed.png

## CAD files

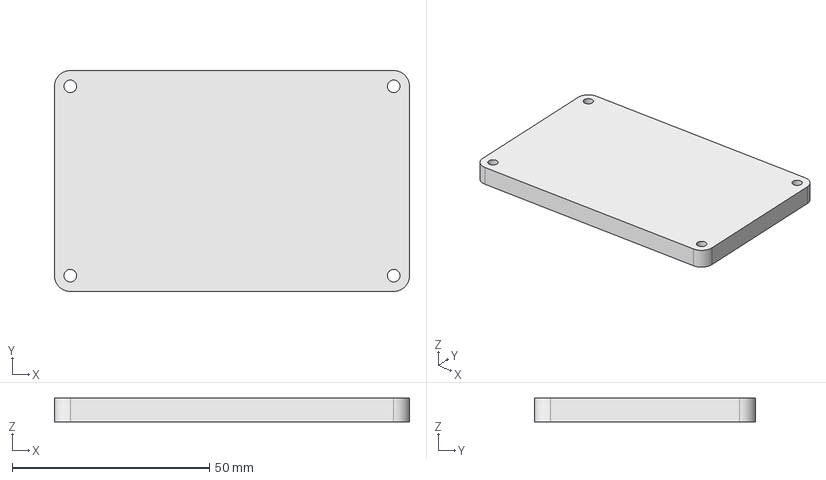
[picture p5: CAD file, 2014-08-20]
MultiSpork/case/mockup-top.FCStd
90.0 x 56.0 x 6.00 mm

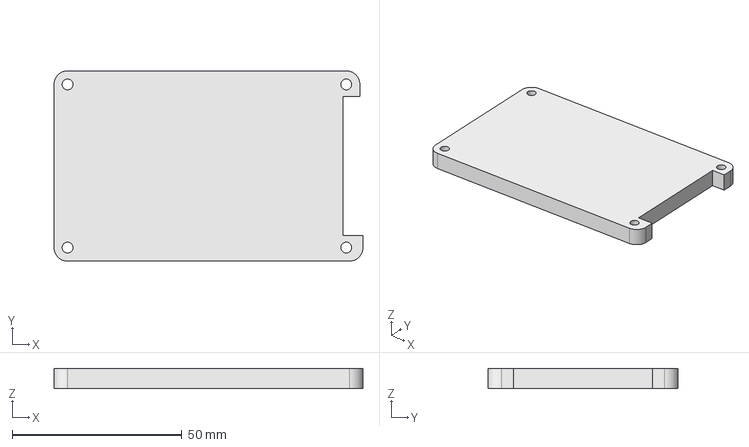
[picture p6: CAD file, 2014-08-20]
MultiSpork/case/mockup-center.FCStd
90.9 x 56.0 x 6.00 mm

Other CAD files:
MultiSpork/case/mockup-center.dxf
MultiSpork/case/mockup-top.dxf

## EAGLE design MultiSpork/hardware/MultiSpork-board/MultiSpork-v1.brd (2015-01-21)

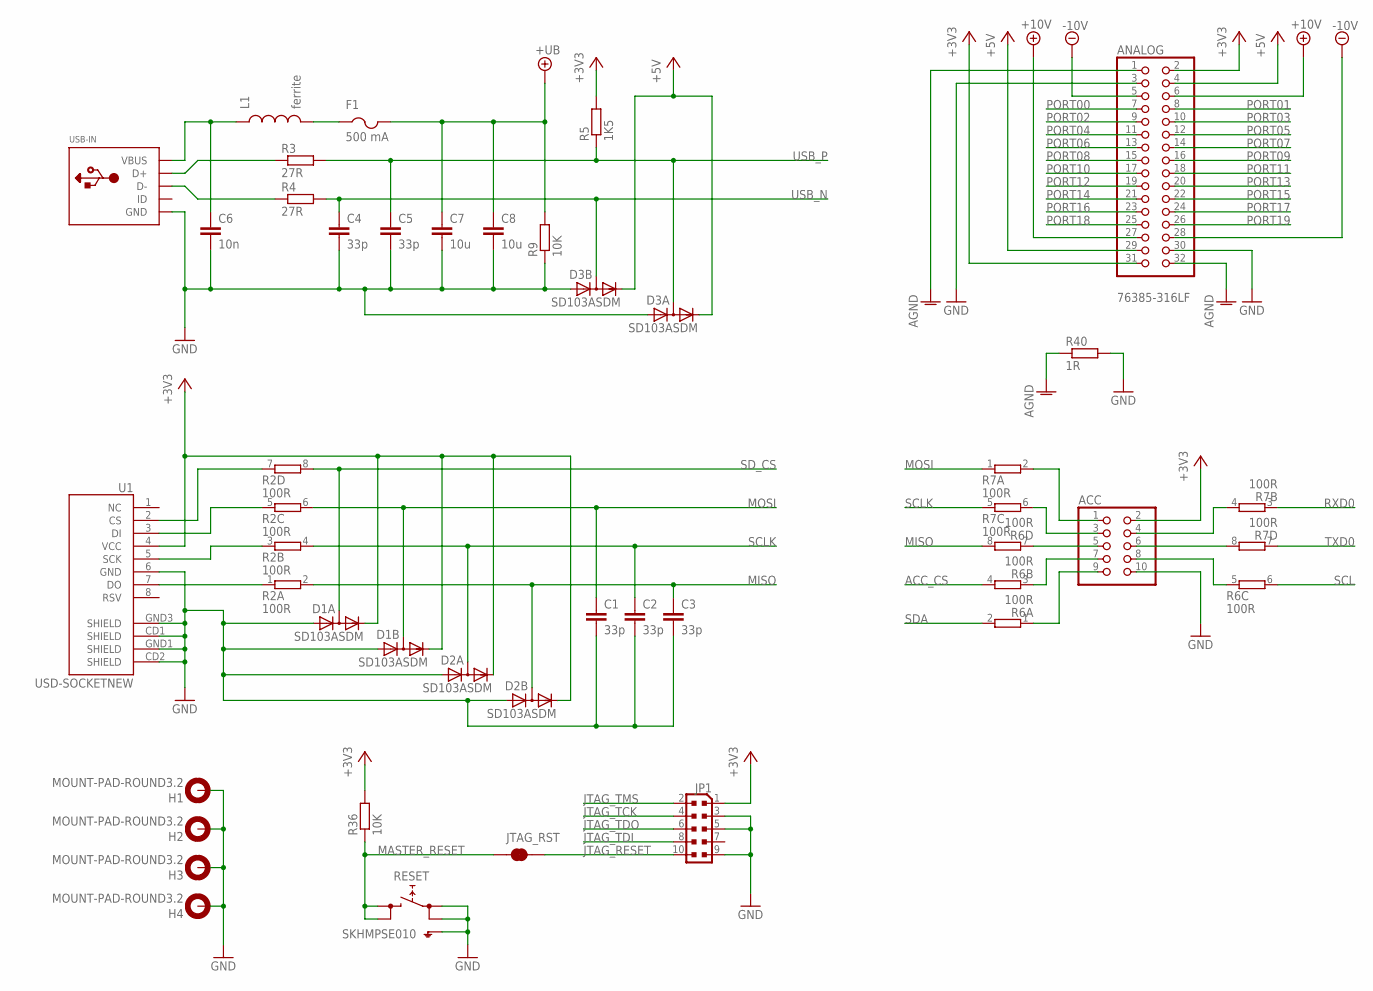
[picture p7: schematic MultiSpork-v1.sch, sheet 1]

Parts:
ACC: PINHD-2X5_2.54; 2X05; PARTNO *
ANALOG: 76385-316LF; 32P-SIDE-SMD; PARTNO 76385-316LF
C1, C2, C3, C4, C5: 33p; C0603; PARTNO VJ0603A330JXACW1BC
C6: 10n; C0603; PARTNO CL10B103KB8NCNC
C7, C8: 10u; C1206; PARTNO C3216X5R1E106M
D1, D2, D3: SD103ASDM; SOT26; PARTNO SD103ASDM-7
F1: 500 mA; R1206; PARTNO 1206L050/15YR
H1, H2, H3, H4: MOUNT-PAD-ROUND3.2; 3,2-PAD; PARTNO *
JP1: PINHEAD_PINHD-2X5PASSO127; PINHEAD_2X05_127; PARTNO M50-3500542
JTAG_RST: JUMPER-PAD-2-NC_BY_TRACE; PAD-JUMPER-2-NC_BY_TRACE_YES_SILK
L1: ferrite; 0805; PARTNO MI0805K400R-10
R2, R6, R7: 100R; CTS742C083-RES; PARTNO 742C083101JPTR
R3, R4: 27R; R0603; PARTNO CRCW060327R0FKEA
R5: 1K5; R0603; PARTNO ERJ-3GEYJ152V
R9, R36: 10K; R0603; PARTNO RNCP0603FTD10K0
R40: 1R; R1206; PARTNO CRCW12061R00FKEA
RESET: SKHMPSE010; SKHMPXE010; PARTNO SKHMQKE010
U1: USD-SOCKETNEW; MICRO-SD-SOCKET-PP; PARTNO 502570-0893
USB-IN: USBMINIB; USB-MINIB; PARTNO 20236

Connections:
+3V3: ACC.2, ANALOG.2, ANALOG.31, D1.2 (C), D1.5 (C), D2.2 (C), D2.5 (C), JP1.1, R5.2, R36.2, U1.4 (VCC); also elsewhere on the board
+5V: ANALOG.4, ANALOG.29, D3.2 (C), D3.5 (C); also elsewhere on the board
+10V: ANALOG.6, ANALOG.27; also elsewhere on the board
+UB: C7.1, C8.1, F1.2, R9.2; also elsewhere on the board
-10V: ANALOG.5, ANALOG.28; also elsewhere on the board
ACC_CS: R6.4 (2); also elsewhere on the board
AGND: ANALOG.1, ANALOG.32, R40.1; also elsewhere on the board
GND: ACC.10, ANALOG.3, ANALOG.30, C1.2, C2.2, C3.2, C4.2, C5.2, C6.2, C7.2, C8.2, D1.3 (A), D1.6 (A), D2.3 (A), D2.6 (A), D3.3 (A), D3.6 (A), H1.B3,2, H2.B3,2, H3.B3,2, H4.B3,2, JP1.3, JP1.5, JP1.9, R9.1, R40.2, RESET.1 (1.1), RESET.2 (1.2), RESET.5 (SH), U1.6 (GND), U1.CD1 (SHIELD), U1.CD2 (SHIELD), U1.GND1 (SHIELD), U1.GND3 (SHIELD), USB-IN.GND; also elsewhere on the board
JTAG_RESET: JP1.10, JTAG_RST.2
JTAG_TCK: JP1.4; also elsewhere on the board
JTAG_TDI: JP1.8; also elsewhere on the board
JTAG_TDO: JP1.6; also elsewhere on the board
JTAG_TMS: JP1.2; also elsewhere on the board
MASTER_RESET: JTAG_RST.1, R36.1, RESET.3 (2.1), RESET.4 (2.2); also elsewhere on the board
MISO: C3.1, D2.1 (AC), R2.2, R6.8 (2); also elsewhere on the board
MOSI: C1.1, D1.1 (AC), R2.6 (2), R7.1; also elsewhere on the board
unnamed: C6.1, L1.1, USB-IN.VBUS
unnamed: R2.7 (1), U1.2 (CS)
unnamed: R2.5 (1), U1.3 (DI)
unnamed: R2.3 (1), U1.5 (SCK)
unnamed: R2.1, U1.7 (DO)
unnamed: R3.1, USB-IN.D+
unnamed: R4.1, USB-IN.D-
unnamed: ACC.1, R7.2
unnamed: ACC.3, R7.6 (2)
unnamed: ACC.5, R6.7 (1)
unnamed: ACC.7, R6.3 (1)
unnamed: ACC.9, R6.1
unnamed: ACC.6, R7.8 (2)
unnamed: ACC.4, R7.4 (2)
unnamed: ACC.8, R6.5 (1)
unnamed: F1.1, L1.2
PORT00: ANALOG.7; also elsewhere on the board
PORT01: ANALOG.8; also elsewhere on the board
PORT02: ANALOG.9; also elsewhere on the board
PORT03: ANALOG.10; also elsewhere on the board
PORT04: ANALOG.11; also elsewhere on the board
PORT05: ANALOG.12; also elsewhere on the board
PORT06: ANALOG.13; also elsewhere on the board
PORT07: ANALOG.14; also elsewhere on the board
PORT08: ANALOG.15; also elsewhere on the board
PORT09: ANALOG.16; also elsewhere on the board
PORT10: ANALOG.17; also elsewhere on the board
PORT11: ANALOG.18; also elsewhere on the board
PORT12: ANALOG.19; also elsewhere on the board
PORT13: ANALOG.20; also elsewhere on the board
PORT14: ANALOG.21; also elsewhere on the board
PORT15: ANALOG.22; also elsewhere on the board
PORT16: ANALOG.23; also elsewhere on the board
PORT17: ANALOG.24; also elsewhere on the board
PORT18: ANALOG.25; also elsewhere on the board
PORT19: ANALOG.26; also elsewhere on the board
RXD0: R7.3 (1); also elsewhere on the board
SCL: R6.6 (2); also elsewhere on the board
SCLK: C2.1, D2.4 (AC), R2.4 (2), R7.5 (1); also elsewhere on the board
SDA: R6.2; also elsewhere on the board
SD_CS: D1.4 (AC), R2.8 (2); also elsewhere on the board
TXD0: R7.7 (1); also elsewhere on the board
USB_N: C4.1, D3.1 (AC), R4.2; also elsewhere on the board
USB_P: C5.1, D3.4 (AC), R3.2, R5.1; also elsewhere on the board

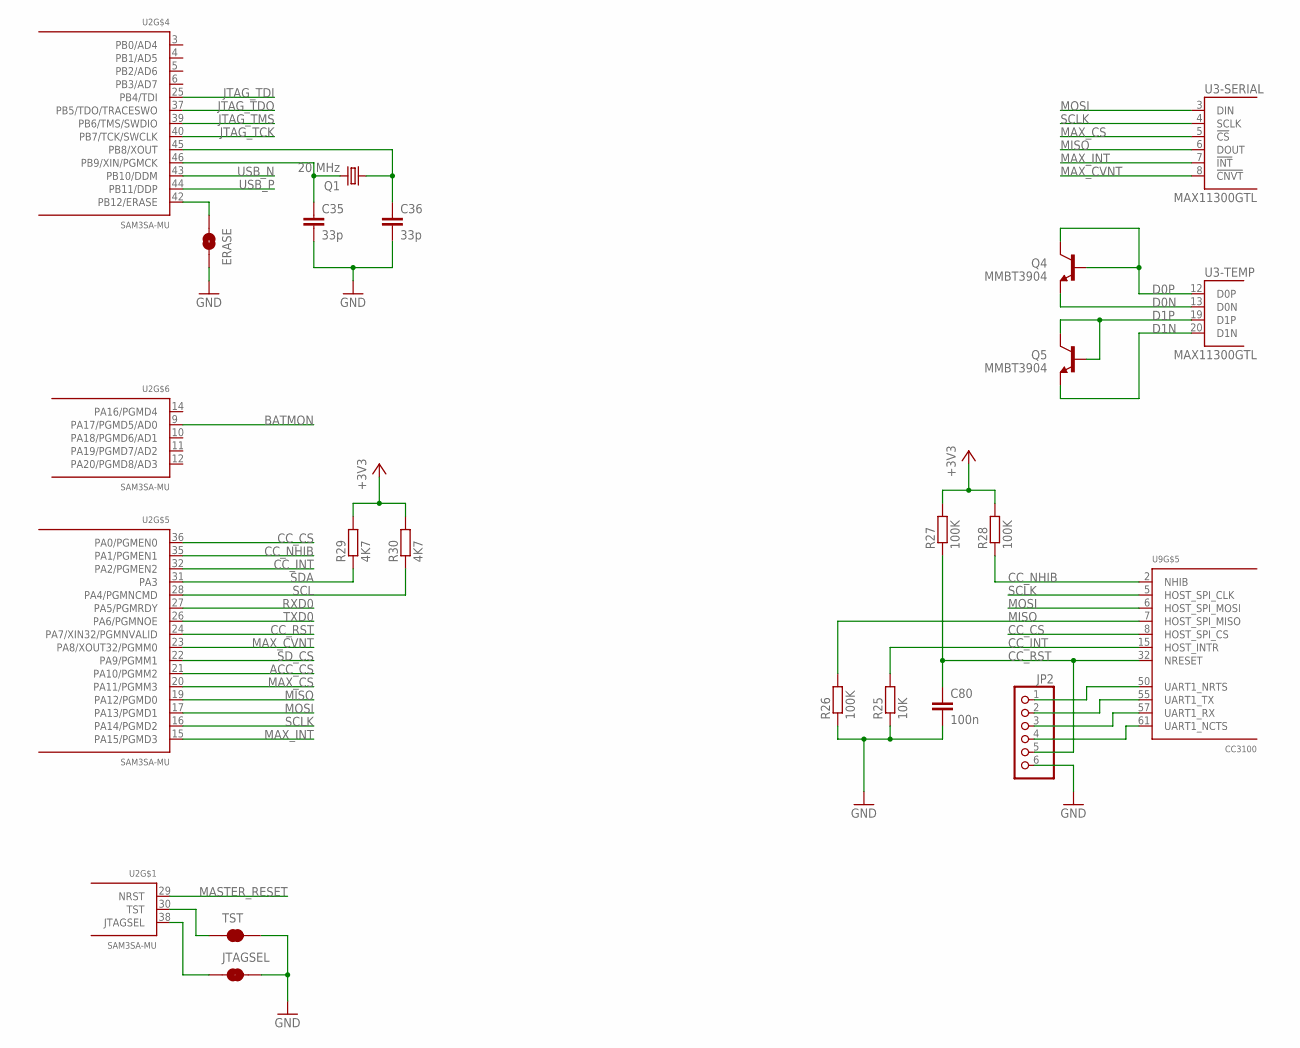
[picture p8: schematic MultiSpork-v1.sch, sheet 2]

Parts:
C35, C36: 33p; C0603; PARTNO VJ0603A330JXACW1BC
C80: 100n; C0603; PARTNO CC0603KRX7R9BB104
ERASE: JUMPER-PAD-2-NOYES_SILK; PAD-JUMPER-2-NO_YES_SILK
JP2: PINHD-1X6; 1X06; PARTNO *
JTAGSEL: JUMPER-PAD-2-NC_BY_TRACE; PAD-JUMPER-2-NC_BY_TRACE_YES_SILK
Q1: 20 MHz; CSM-3X; PARTNO ECS-200-20-3X-TR
Q4, Q5: MMBT3904; SOT23; PARTNO MMBT3904
R25: 10K; R0603; PARTNO RNCP0603FTD10K0
R26, R27, R28: 100K; R0603; PARTNO CRCW0603100KFKEA
R29, R30: 4K7; R0603; PARTNO RC1608J472CS
TST: JUMPER-PAD-2-NC_BY_TRACE; PAD-JUMPER-2-NC_BY_TRACE_YES_SILK
U2: SAM3SA-MU; QFN48; PARTNO ATSAM3S4AA-MU
U3: MAX11300GTL; TQFN40; PARTNO MAX11300GTL+
U9: CC3100; QFN64; PARTNO CC3100

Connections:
+3V3: R27.2, R28.2, R29.2, R30.2; also elsewhere on the board
ACC_CS: U2.21 (PA10/PGMM2); also elsewhere on the board
BATMON: U2.9 (PA17/PGMD5/AD0); also elsewhere on the board
CC_CS: U2.36 (PA0/PGMEN0), U9.8 (HOST_SPI_CS)
CC_INT: R25.2, U2.32 (PA2/PGMEN2), U9.15 (HOST_INTR)
CC_NHIB: R28.1, U2.35 (PA1/PGMEN1), U9.2 (NHIB)
CC_RST: C80.1, JP2.5, R27.1, U2.24 (PA7/XIN32/PGMNVALID), U9.32 (NRESET)
D0N: Q4.2 (E), U3.13 (D0N)
D0P: Q4.1 (B), Q4.3 (C), U3.12 (D0P)
D1N: Q5.2 (E), U3.20 (D1N)
D1P: Q5.1 (B), Q5.3 (C), U3.19 (D1P)
DCDC_ANA2_SW_N: U9.46 (DCDC_ANA2_SW_N)
DCDC_ANA2_SW_P: U9.45 (DCDC_ANA2_SW_P)
GND: C35.2, C36.2, C80.2, ERASE.2, JP2.6, JTAGSEL.2, R25.1, R26.1, TST.2; also elsewhere on the board
JTAG_TCK: U2.40 (PB7/TCK/SWCLK); also elsewhere on the board
JTAG_TDI: U2.25 (PB4/TDI); also elsewhere on the board
JTAG_TDO: U2.37 (PB5/TDO/TRACESWO); also elsewhere on the board
JTAG_TMS: U2.39 (PB6/TMS/SWDIO); also elsewhere on the board
MASTER_RESET: U2.29 (NRST); also elsewhere on the board
MAX_CS: U2.20 (PA11/PGMM3), U3.5 (!CS!)
MAX_CVNT: U2.23 (PA8/XOUT32/PGMM0), U3.8 (!CNVT!)
MAX_INT: U2.15 (PA15/PGMD3), U3.7 (!INT!)
MISO: R26.2, U2.19 (PA12/PGMD0), U3.6 (DOUT), U9.7 (HOST_SPI_MISO); also elsewhere on the board
MOSI: U2.17 (PA13/PGMD1), U3.3 (DIN), U9.6 (HOST_SPI_MOSI); also elsewhere on the board
unnamed: C35.1, Q1.2, U2.46 (PB9/XIN/PGMCK)
unnamed: C36.1, Q1.1, U2.45 (PB8/XOUT)
unnamed: TST.1, U2.30 (TST)
unnamed: JTAGSEL.1, U2.38 (JTAGSEL)
unnamed: ERASE.1, U2.42 (PB12/ERASE)
unnamed: JP2.1, U9.50 (UART1_NRTS)
unnamed: JP2.2, U9.55 (UART1_TX)
unnamed: JP2.3, U9.57 (UART1_RX)
unnamed: JP2.4, U9.61 (UART1_NCTS)
RXD0: U2.27 (PA5/PGMRDY); also elsewhere on the board
SCL: R30.1, U2.28 (PA4/PGMNCMD); also elsewhere on the board
SCLK: U2.16 (PA14/PGMD2), U3.4 (SCLK), U9.5 (HOST_SPI_CLK); also elsewhere on the board
SDA: R29.1, U2.31 (PA3); also elsewhere on the board
SD_CS: U2.22 (PA9/PGMM1); also elsewhere on the board
TXD0: U2.26 (PA6/PGMNOE); also elsewhere on the board
USB_N: U2.43 (PB10/DDM); also elsewhere on the board
USB_P: U2.44 (PB11/DDP); also elsewhere on the board

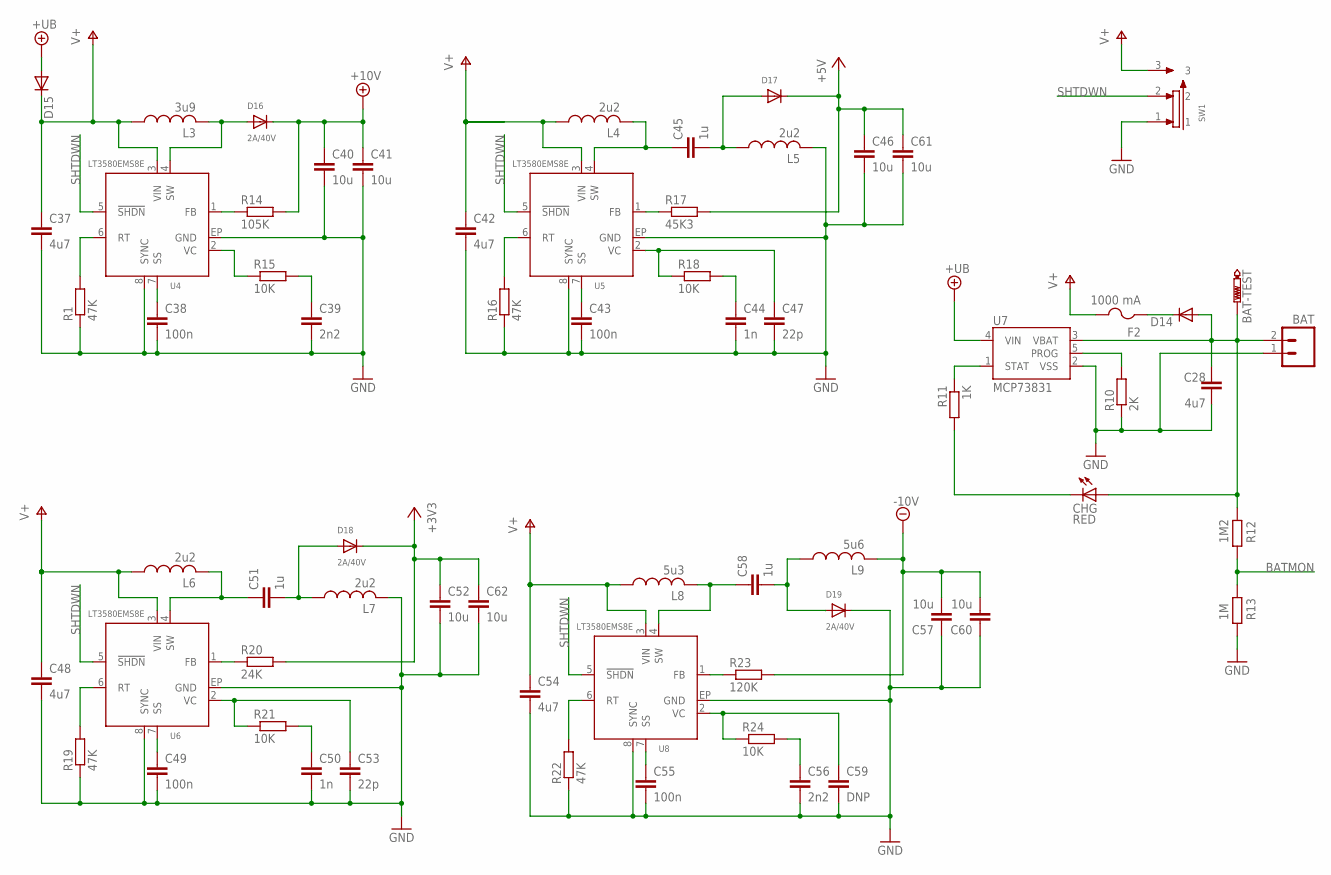
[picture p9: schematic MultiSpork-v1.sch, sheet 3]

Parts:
BAT: M02-JST-2MM-SMT; S2B-PH; PARTNO S2B-PH-SM4-TB(LF)(SN)
BAT-TEST: PTR1TP13SQ; TP13SQ; PARTNO TP13
C28: 4u7; C1206; PARTNO C3216Y5V1H475Z
C37, C42, C48, C54: 4u7; C1210; PARTNO TMK325B7475KN-T
C38, C43, C49, C55: 100n; C0603; PARTNO CC0603KRX7R9BB104
C39, C56: 2n2; C0603; PARTNO VJ0603Y222KXACW1BC
C40, C41, C46, C52, C57, C60, C61, C62: 10u; C1210; PARTNO UMK325BJ106MM
C44, C50: 1n; C0603; PARTNO UMK107SD102KA-T
C45, C51, C58: 1u; C1210; PARTNO TMK325B7105KD-T
C47, C53: 22p; C0603; PARTNO GQM1885C1H220JB01D
C59: DNP; C0603; PARTNO DNP
CHG: RED; CHIP-LED0603; PARTNO LTST-C193KRKT-5A
D14, D15: DIODE-SMB; SMB; PARTNO LSM115JE3
D16, D18, D19: 2A/40V; SMADIODE; PARTNO CD214A-B240LLF
D17: DIODESOD-123; SOD-123; PARTNO PMEG3020ER,115
F2: 1000 mA; R1206; PARTNO 0ZCJ0100FF2E
L3: 3u9; L2323; PARTNO SRR5018-3R9Y
L4, L5, L6, L7: 2u2; L1008; PARTNO 252012CDMCDS-2R2MC
L8: 5u3; L2323; PARTNO SRR5028-5R3Y
L9: 5u6; L1008; PARTNO 1008 (2520 metric)
R1, R16, R19, R22: 47K; R0603; PARTNO MCT06030C4702FP500
R10: 2K; R0603; PARTNO RC0603FR-072KL
R11: 1K; R0603; PARTNO RMCF0603FT1K00
R12: 1M2; R0603; PARTNO ERJ-3EKF1204V
R13: 1M; R0603; PARTNO ERJ-3EKF1004V
R14: 105K; R0603; PARTNO CRCW0603105KFKEA
R15, R18, R21, R24: 10K; R0603; PARTNO RNCP0603FTD10K0
R17: 45K3; R0603; PARTNO CRCW060345K3FKEA
R20: 24K; R0603; PARTNO CRCW060324K0FKEA
R23: 120K; R0603; PARTNO AF0603FR-07120KL
SW1: JS102011SAQN; PARTNO JS102011SAQN
U4, U5, U6, U8: LT3580EMS8E; MSOP8; PARTNO LT3580EMS8E#PBF
U7: MCP73831; SOT23-5; PARTNO MCP73831T-2ACI/OT

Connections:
+3V3: C52.1, C62.1, D18.C, R20.2; also elsewhere on the board
+5V: C46.1, C61.1, D17.C, R17.2; also elsewhere on the board
+10V: C40.1, C41.1, D16.C, R14.2; also elsewhere on the board
+UB: D15.A, U7.4 (VIN); also elsewhere on the board
-10V: C57.2, C60.2, L9.2, R23.2; also elsewhere on the board
BATMON: R12.2, R13.1; also elsewhere on the board
GND: BAT.1, C28.2, C37.2, C38.2, C39.2, C40.2, C41.2, C42.2, C43.2, C44.2, C46.2, C47.2, C48.2, C49.2, C50.2, C52.2, C53.2, C54.2, C55.2, C56.2, C57.1, C59.2, C60.1, C61.2, C62.2, D19.C, L5.2, L7.2, R1.1, R10.1, R13.2, R16.1, R19.1, R22.1, SW1.1, U4.8 (SYNC), U4.EP (GND), U5.8 (SYNC), U5.EP (GND), U6.8 (SYNC), U6.EP (GND), U7.2 (VSS), U8.8 (SYNC), U8.EP (GND); also elsewhere on the board
unnamed: C38.1, U4.7 (SS)
unnamed: R1.2, U4.6 (RT)
unnamed: R14.1, U4.1 (FB)
unnamed: R15.1, U4.2 (VC)
unnamed: C39.1, R15.2
unnamed: C43.1, U5.7 (SS)
unnamed: D16.A, L3.4 (2), U4.4 (SW)
unnamed: R16.2, U5.6 (RT)
unnamed: R17.1, U5.1 (FB)
unnamed: R10.2, U7.5 (PROG)
unnamed: R11.1, U7.1 (STAT)
unnamed: CHG.C, R11.2
unnamed: D14.C, F2.1
unnamed: C47.1, R18.1, U5.2 (VC)
unnamed: C44.1, R18.2
unnamed: C45.1, L4.2, U5.4 (SW)
unnamed: C45.2, D17.A, L5.1
unnamed: C55.1, U8.7 (SS)
unnamed: R22.2, U8.6 (RT)
unnamed: R23.1, U8.1 (FB)
unnamed: C49.1, U6.7 (SS)
unnamed: R19.2, U6.6 (RT)
unnamed: R20.1, U6.1 (FB)
unnamed: C53.1, R21.1, U6.2 (VC)
unnamed: C50.1, R21.2
unnamed: C51.1, L6.2, U6.4 (SW)
unnamed: C51.2, D18.A, L7.1
unnamed: C59.1, R24.1, U8.2 (VC)
unnamed: C56.1, R24.2
unnamed: C58.1, L8.4 (2), U8.4 (SW)
unnamed: C58.2, D19.A, L9.1
SHTDWN: SW1.2, U4.5 (!SHDN!), U5.5 (!SHDN!), U6.5 (!SHDN!), U8.5 (!SHDN!)
V+: C37.1, C42.1, C48.1, C54.1, D15.C, F2.2, L3.3 (1), L4.1, L6.1, L8.3 (1), SW1.3, U4.3 (VIN), U5.3 (VIN), U6.3 (VIN), U8.3 (VIN)
VBAT1: BAT.2, BAT-TEST.TP, C28.1, CHG.A, D14.A, R12.1, U7.3 (VBAT)

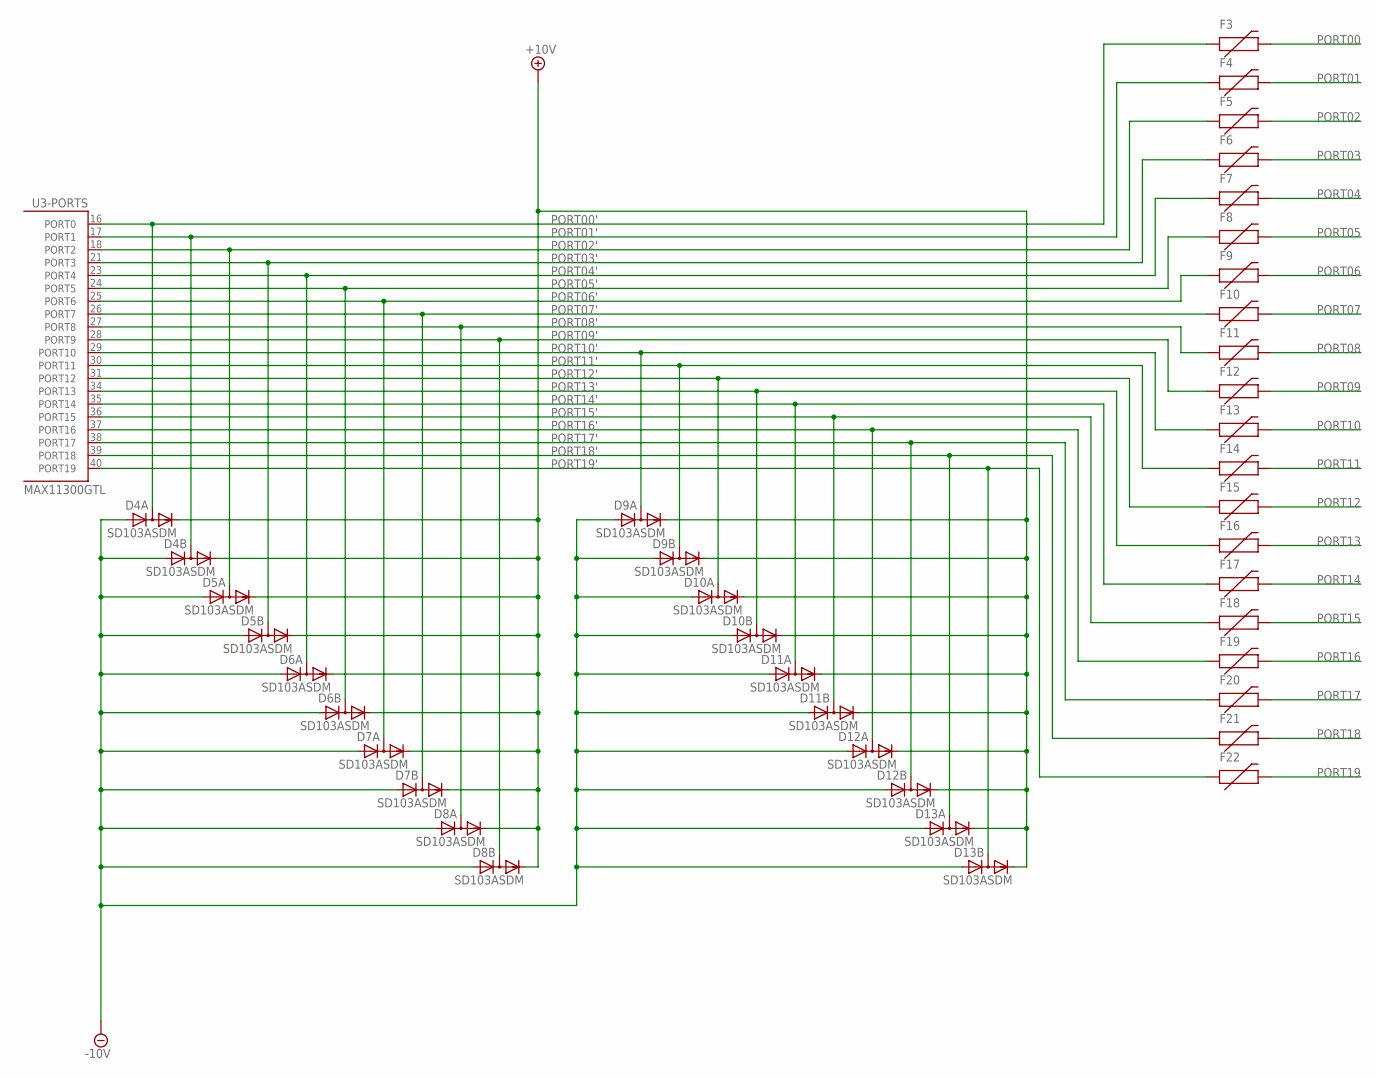
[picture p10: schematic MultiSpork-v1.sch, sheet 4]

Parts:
D4, D5, D6, D7, D8, D9, D10, D11, D12, D13: SD103ASDM; SOT26; PARTNO SD103ASDM-7
F3, F4, F5, F6, F7, F8, F9, F10, F11, F12, F13, F14, F15, F16, F17, F18, F19, F20, F21, F22: PTC0603; 0603; PARTNO femtoSMDC008F-02
U3: MAX11300GTL; TQFN40; PARTNO MAX11300GTL+

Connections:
+10V: D4.2 (C), D4.5 (C), D5.2 (C), D5.5 (C), D6.2 (C), D6.5 (C), D7.2 (C), D7.5 (C), D8.2 (C), D8.5 (C), D9.2 (C), D9.5 (C), D10.2 (C), D10.5 (C), D11.2 (C), D11.5 (C), D12.2 (C), D12.5 (C), D13.2 (C), D13.5 (C); also elsewhere on the board
-10V: D4.3 (A), D4.6 (A), D5.3 (A), D5.6 (A), D6.3 (A), D6.6 (A), D7.3 (A), D7.6 (A), D8.3 (A), D8.6 (A), D9.3 (A), D9.6 (A), D10.3 (A), D10.6 (A), D11.3 (A), D11.6 (A), D12.3 (A), D12.6 (A), D13.3 (A), D13.6 (A); also elsewhere on the board
PORT00: F3.2; also elsewhere on the board
PORT00': D4.4 (AC), F3.1, U3.16 (PORT0)
PORT01: F4.2; also elsewhere on the board
PORT01': D4.1 (AC), F4.1, U3.17 (PORT1)
PORT02: F5.2; also elsewhere on the board
PORT02': D5.4 (AC), F5.1, U3.18 (PORT2)
PORT03: F6.2; also elsewhere on the board
PORT03': D5.1 (AC), F6.1, U3.21 (PORT3)
PORT04: F7.2; also elsewhere on the board
PORT04': D6.4 (AC), F7.1, U3.23 (PORT4)
PORT05: F8.2; also elsewhere on the board
PORT05': D6.1 (AC), F8.1, U3.24 (PORT5)
PORT06: F9.2; also elsewhere on the board
PORT06': D7.4 (AC), F9.1, U3.25 (PORT6)
PORT07: F10.2; also elsewhere on the board
PORT07': D7.1 (AC), F10.1, U3.26 (PORT7)
PORT08: F11.2; also elsewhere on the board
PORT08': D8.4 (AC), F11.1, U3.27 (PORT8)
PORT09: F12.2; also elsewhere on the board
PORT09': D8.1 (AC), F12.1, U3.28 (PORT9)
PORT10: F13.2; also elsewhere on the board
PORT10': D9.4 (AC), F13.1, U3.29 (PORT10)
PORT11: F14.2; also elsewhere on the board
PORT11': D9.1 (AC), F14.1, U3.30 (PORT11)
PORT12: F15.2; also elsewhere on the board
PORT12': D10.4 (AC), F15.1, U3.31 (PORT12)
PORT13: F16.2; also elsewhere on the board
PORT13': D10.1 (AC), F16.1, U3.34 (PORT13)
PORT14: F17.2; also elsewhere on the board
PORT14': D11.4 (AC), F17.1, U3.35 (PORT14)
PORT15: F18.2; also elsewhere on the board
PORT15': D11.1 (AC), F18.1, U3.36 (PORT15)
PORT16: F19.2; also elsewhere on the board
PORT16': D12.4 (AC), F19.1, U3.37 (PORT16)
PORT17: F20.2; also elsewhere on the board
PORT17': D12.1 (AC), F20.1, U3.38 (PORT17)
PORT18: F21.2; also elsewhere on the board
PORT18': D13.4 (AC), F21.1, U3.39 (PORT18)
PORT19: F22.2; also elsewhere on the board
PORT19': D13.1 (AC), F22.1, U3.40 (PORT19)

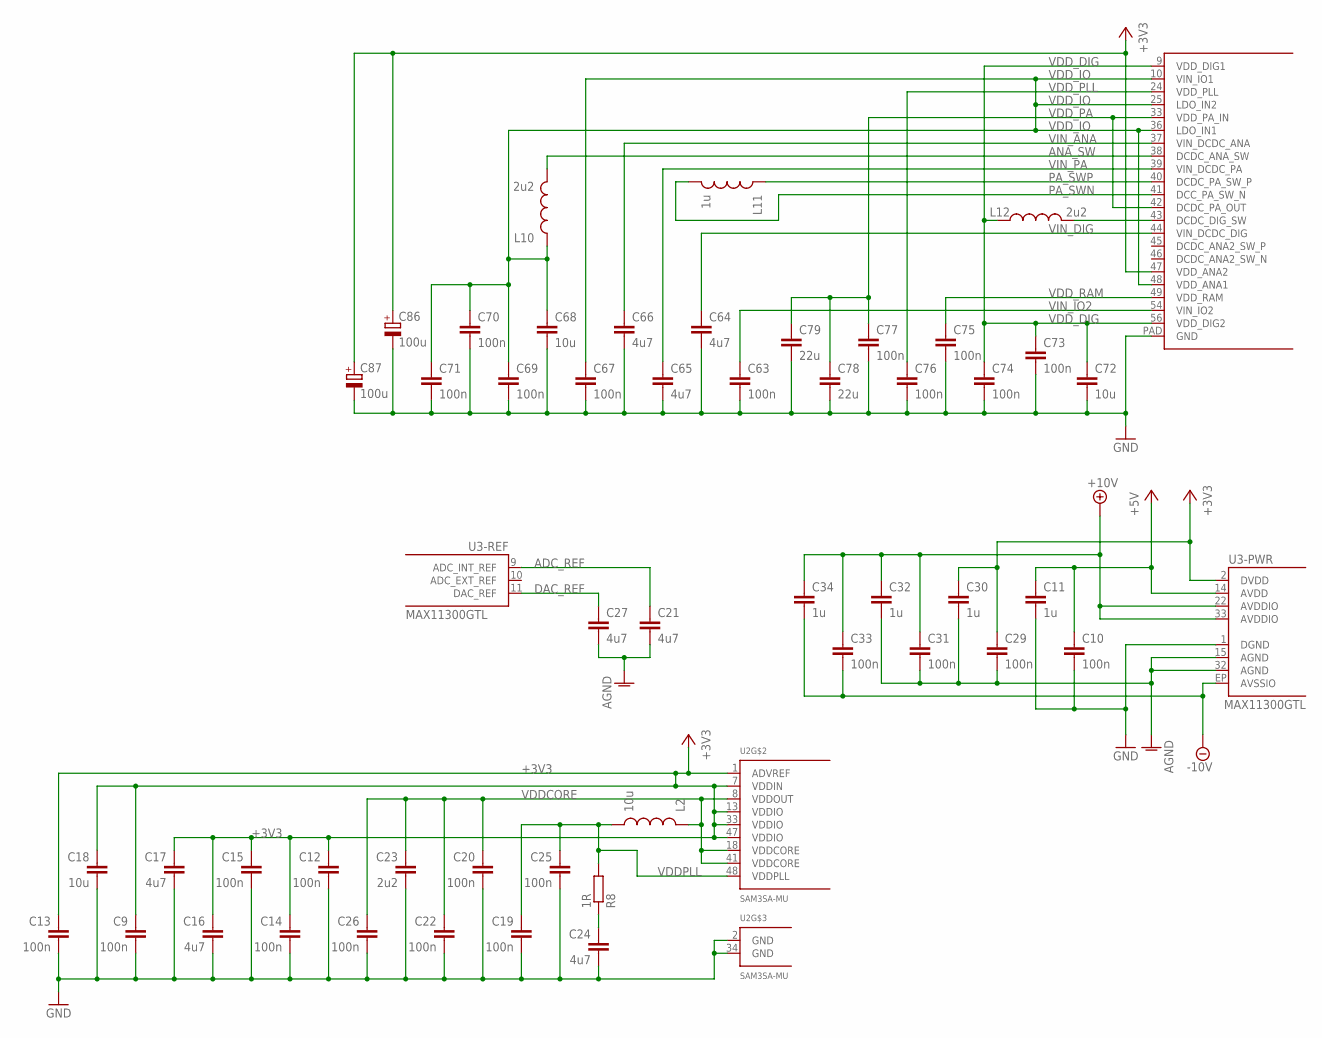
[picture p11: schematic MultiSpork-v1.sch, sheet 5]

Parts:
C9, C10, C12, C13, C14, C15, C19, C20, C22, C25, C26, C29, C31, C33, C63, C67, C69, C70, C71, C73, C74, C75, C76, C77: 100n; C0603; PARTNO CC0603KRX7R9BB104
C11, C30, C32, C34: 1u; C0603; PARTNO UMK107BJ105KA-T
C16, C17, C21, C24, C27, C64, C65, C66: 4u7; C0603; PARTNO GRM188F51A475ZE20D
C18, C68, C72: 10u; C0603; PARTNO EMK107BBJ106MA-T
C23: 2u2; C0603; PARTNO C1608X7R1A225K
C78, C79: 22u; C1206; PARTNO GRM31CR61C226ME15L
C86, C87: 100u; CT6032; PARTNO TAJC107K016RNJ
L2: 10u; INDUCTOR-1206; PARTNO LQH31CN100K03L
L10, L12: 2u2; INDUCTOR-1206; PARTNO LQM31PN2R2M00L
L11: 1u; INDUCTOR-1206; PARTNO LQM31PN1R0MC0L
R8: 1R; R0603; PARTNO ERJ-3GEYJ1R0V
U2: SAM3SA-MU; QFN48; PARTNO ATSAM3S4AA-MU
U3: MAX11300GTL; TQFN40; PARTNO MAX11300GTL+
U9: CC3100; QFN64; PARTNO CC3100

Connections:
+3V3: C9.1, C12.1, C13.1, C14.1, C15.1, C16.1, C17.1, C18.1, C29.1, C30.1, C86.+, C87.+, U2.1 (ADVREF), U2.7 (VDDIN), U2.13 (VDDIO), U2.33 (VDDIO), U2.47 (VDDIO), U3.2 (DVDD), U9.47 (VDD_ANA2); also elsewhere on the board
+5V: C10.1, C11.1, U3.14 (AVDD); also elsewhere on the board
+10V: C31.1, C32.1, C33.1, C34.1, U3.22 (AVDDIO), U3.33 (AVDDIO); also elsewhere on the board
-10V: C33.2, C34.2, U3.EP (AVSSIO); also elsewhere on the board
ADC_REF: C21.1, U3.9 (ADC_INT_REF)
AGND: C21.2, C27.2, C29.2, C30.2, C31.2, C32.2, U3.15 (AGND), U3.32 (AGND); also elsewhere on the board
ANA_SW: L10.P$2 (2), U9.38 (DCDC_ANA_SW)
DAC_REF: C27.1, U3.11 (DAC_REF)
DCDC_ANA2_SW_N: U9.46 (DCDC_ANA2_SW_N)
DCDC_ANA2_SW_P: U9.45 (DCDC_ANA2_SW_P)
GND: C9.2, C10.2, C11.2, C12.2, C13.2, C14.2, C15.2, C16.2, C17.2, C18.2, C19.2, C20.2, C22.2, C23.2, C24.2, C25.2, C26.2, C63.2, C64.2, C65.2, C66.2, C67.2, C68.2, C69.2, C70.2, C71.2, C72.2, C73.2, C74.2, C75.2, C76.2, C77.2, C78.2, C79.2, C86.-, C87.-, U2.2 (GND), U2.34 (GND), U3.1 (DGND), U9.PAD (GND); also elsewhere on the board
unnamed: L12.P$2 (2), U9.43 (DCDC_DIG_SW)
PA_SWN: L11.P$2 (2), U9.41 (DCC_PA_SW_N)
PA_SWP: L11.P$1 (1), U9.40 (DCDC_PA_SW_P)
PLL-GND: C24.1, R8.1
VDDCORE: C20.1, C22.1, C23.1, C26.1, L2.P$1 (1), U2.8 (VDDOUT), U2.18 (VDDCORE), U2.41 (VDDCORE)
VDDPLL: C19.1, C25.1, L2.P$2 (2), R8.2, U2.48 (VDDPLL)
VDD_DIG: C72.1, C73.1, C74.1, L12.P$1 (1), U9.9 (VDD_DIG1), U9.56 (VDD_DIG2)
VDD_IO: C67.1, C68.1, C69.1, C70.1, C71.1, L10.P$1 (1), U9.10 (VIN_IO1), U9.25 (LDO_IN2), U9.36 (LDO_IN1), U9.48 (VDD_ANA1)
VDD_PA: C77.1, C78.1, C79.1, U9.33 (VDD_PA_IN), U9.42 (DCDC_PA_OUT)
VDD_PLL: C76.1, U9.24 (VDD_PLL)
VDD_RAM: C75.1, U9.49 (VDD_RAM)
VIN_ANA: C66.1, U9.37 (VIN_DCDC_ANA)
VIN_DIG: C64.1, U9.44 (VIN_DCDC_DIG)
VIN_IO2: C63.1, U9.54 (VIN_IO2)
VIN_PA: C65.1, U9.39 (VIN_DCDC_PA)

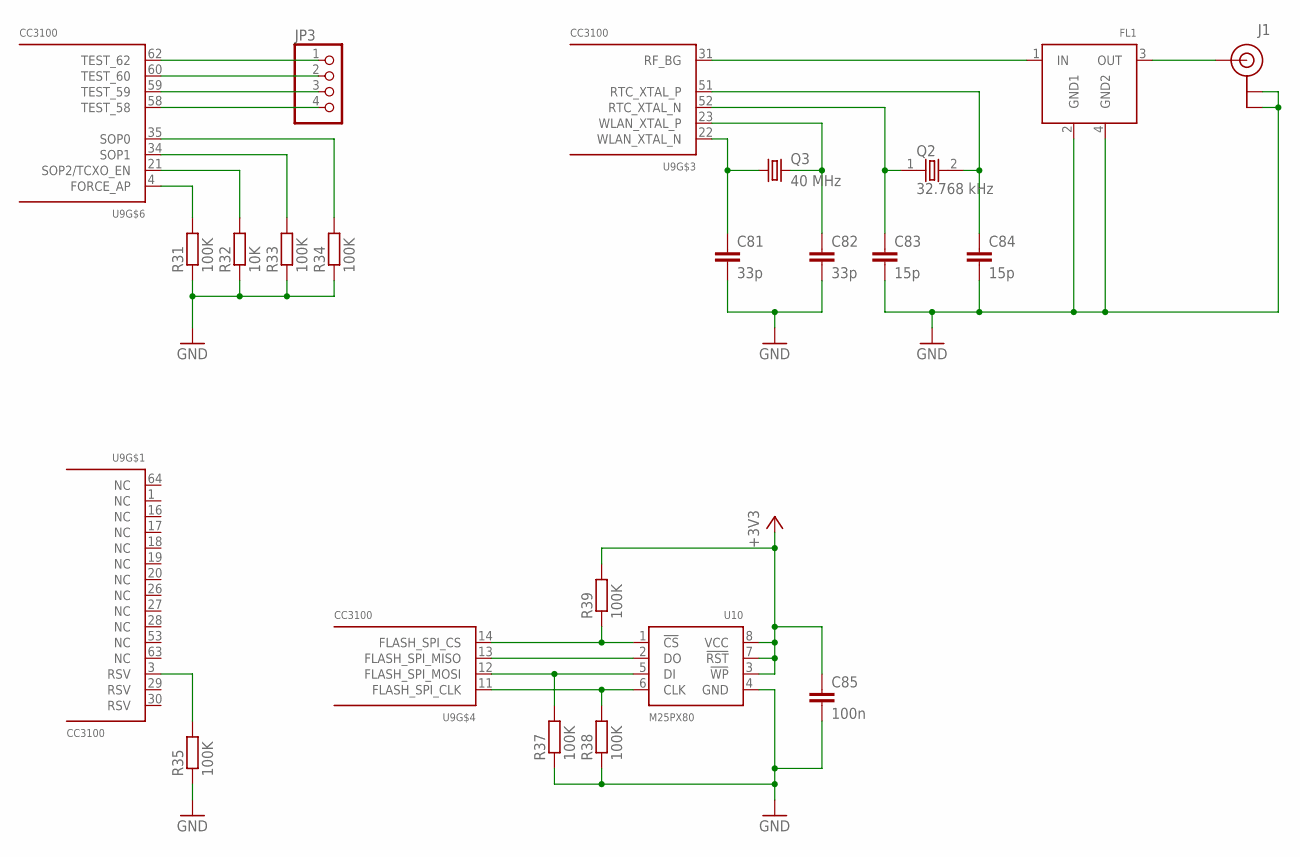
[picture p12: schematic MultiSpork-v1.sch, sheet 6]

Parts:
C81, C82: 33p; C0603; PARTNO VJ0603A330JXACW1BC
C83, C84: 15p; C0603; PARTNO VJ0603A150JXACW1BC
C85: 100n; C0603; PARTNO CC0603KRX7R9BB104
FL1: DEA202450BT; PARTNO DEA202450BT-7210A1
J1: U.FL; PARTNO U.FL-R-SMT(10)
JP3: PINHD-1X4; 1X04; PARTNO *
Q2: 32.768 kHz; ECX-31B; PARTNO ECS-.327-7-34B-TR
Q3: 40 MHz; CSM-3X; PARTNO ECS-400-20-3X-EN-TR
R31, R33, R34, R35, R37, R38, R39: 100K; R0603; PARTNO CRCW0603100KFKEA
R32: 10K; R0603; PARTNO RNCP0603FTD10K0
U9: CC3100; QFN64; PARTNO CC3100
U10: M25PX80; SOIC8; PARTNO M25PX80-VMN6TP

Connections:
+3V3: C85.1, R39.2, U10.3 (!WP!), U10.7 (!RST!), U10.8 (VCC); also elsewhere on the board
DCDC_ANA2_SW_N: U9.46 (DCDC_ANA2_SW_N)
DCDC_ANA2_SW_P: U9.45 (DCDC_ANA2_SW_P)
GND: C81.2, C82.2, C83.2, C84.2, C85.2, FL1.2 (GND1), FL1.4 (GND2), J1.P$1 (GND), J1.P$2 (GND), R31.1, R32.1, R33.1, R34.1, R35.1, R37.1, R38.1, U10.4 (GND); also elsewhere on the board
unnamed: R38.2, U9.11 (FLASH_SPI_CLK), U10.6 (CLK)
unnamed: R31.2, U9.4 (FORCE_AP)
unnamed: R32.2, U9.21 (SOP2/TCXO_EN)
unnamed: R33.2, U9.34 (SOP1)
unnamed: R34.2, U9.35 (SOP0)
unnamed: R37.2, U9.12 (FLASH_SPI_MOSI), U10.5 (DI)
unnamed: JP3.1, U9.62 (TEST_62)
unnamed: JP3.2, U9.60 (TEST_60)
unnamed: JP3.3, U9.59 (TEST_59)
unnamed: JP3.4, U9.58 (TEST_58)
unnamed: R35.2, U9.3 (RSV)
unnamed: C81.1, Q3.1, U9.22 (WLAN_XTAL_N)
unnamed: C82.1, Q3.2, U9.23 (WLAN_XTAL_P)
unnamed: C83.1, Q2.1, U9.52 (RTC_XTAL_N)
unnamed: C84.1, Q2.2, U9.51 (RTC_XTAL_P)
unnamed: U9.13 (FLASH_SPI_MISO), U10.2 (DO)
unnamed: R39.1, U9.14 (FLASH_SPI_CS), U10.1 (!CS!)
unnamed: FL1.1 (IN), U9.31 (RF_BG)
unnamed: FL1.3 (OUT), J1.P$3 (SIGNAL)

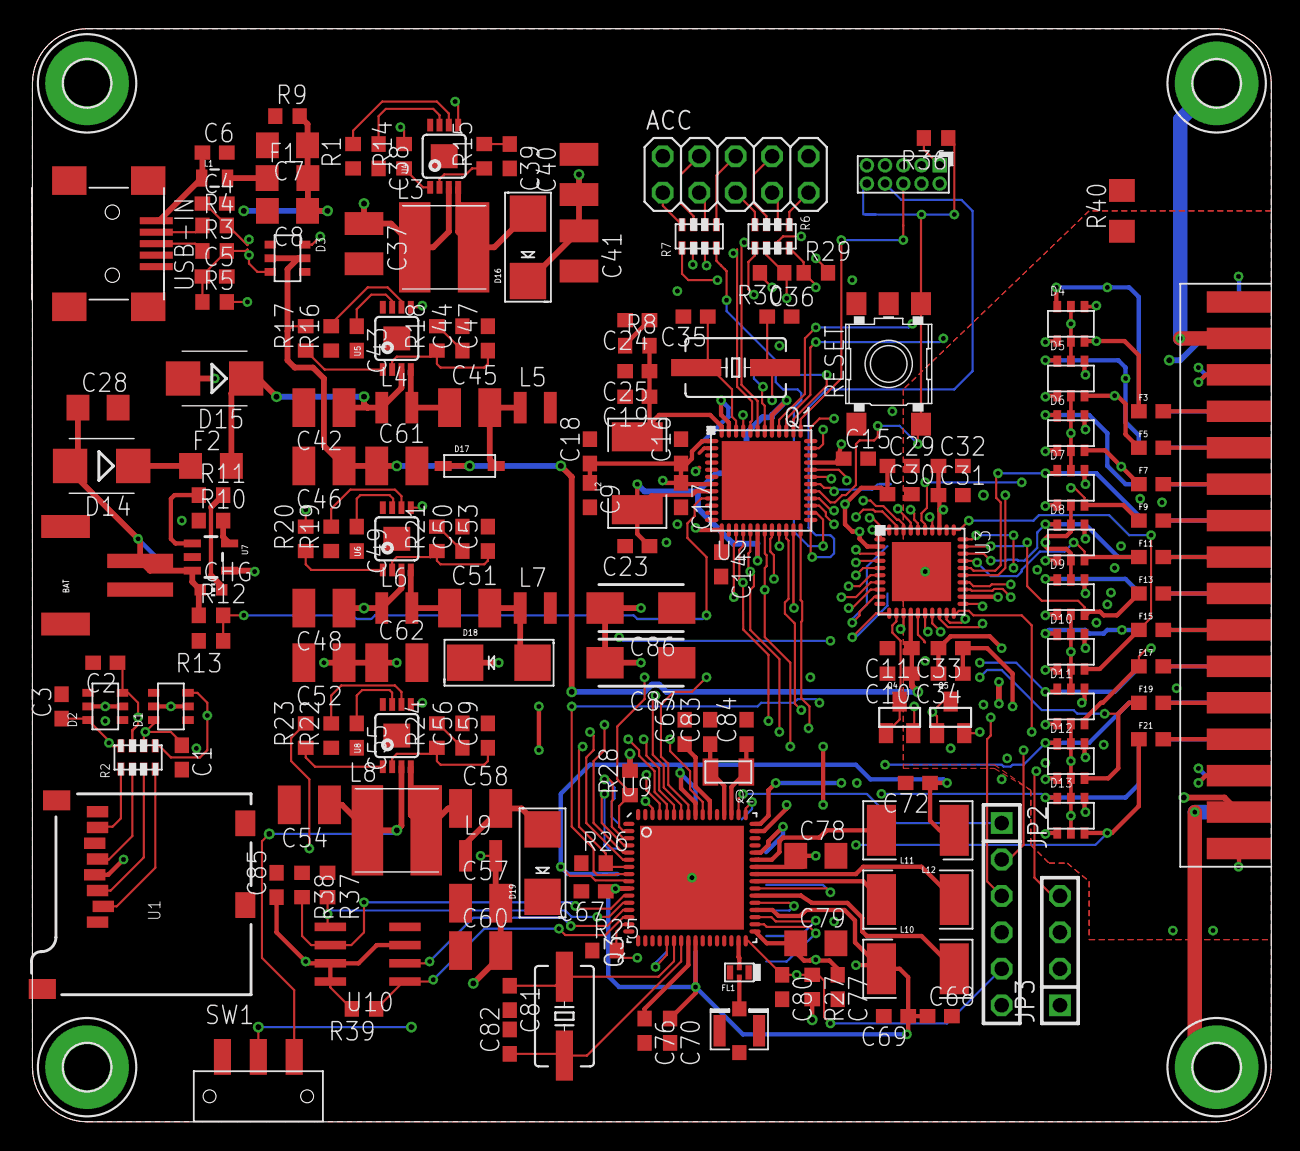
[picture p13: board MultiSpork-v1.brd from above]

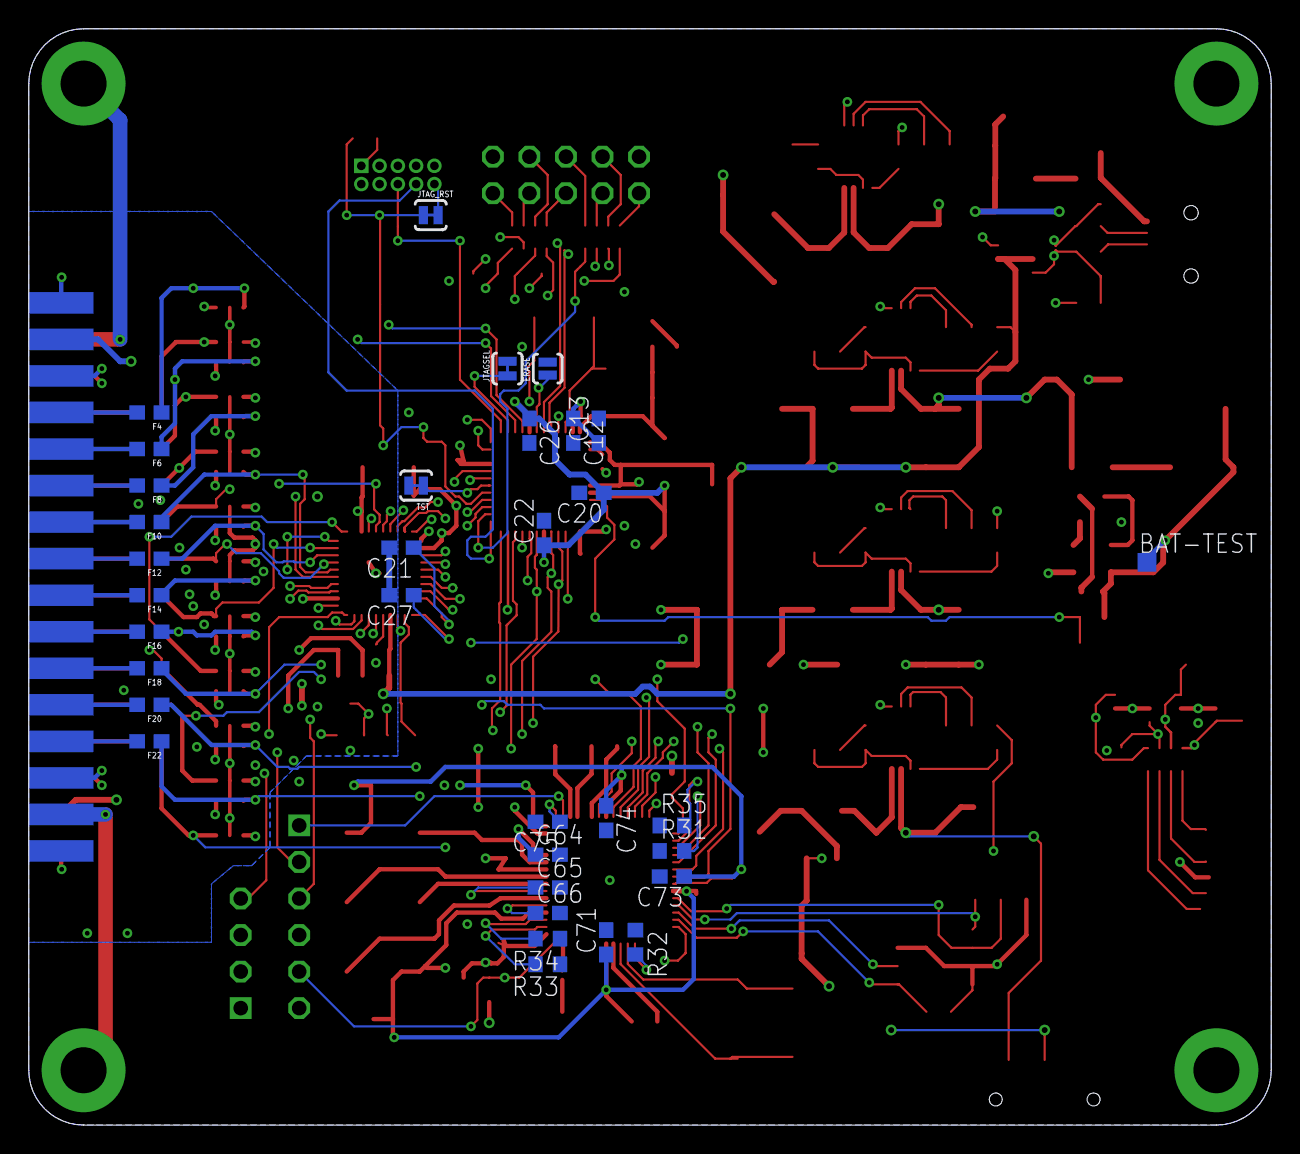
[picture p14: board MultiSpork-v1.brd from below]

Board: 4 copper layers, 86.4 x 76.2 mm, 216 parts (34 on the bottom side), 172 nets.

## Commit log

2014-07-26 First check-in of schematic, board, and special libraries
    [MultiSpork-v1.brd, MultiSpork-v1.sch]
2014-07-26 First check-in of switching regulator design sheet for the LT3580
    [regulator-design-sheet.xlsx]
2014-07-26 Updated hardware block diagram such that: -- External power is through USB or battery -- Adding a battery charger block
2014-07-28 Finished design sheet to use a common design for all four regulators
    [regulator-design-sheet.xlsx]
2014-07-28 Updated board with: -- Voltage regulators -- CC3100 WiFi
    [MultiSpork-v1.brd, MultiSpork-v1.sch]
2014-07-28 -- Added flash chip to CC3100.lbr -- Added 2.4 GHz filter to CC3100.lbr -- Added RF components on schematic -- Added CC3100 crystals on schematic -- Added MAX11300 external temperature sensors -- Fix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
    [MultiSpork-v1.brd, MultiSpork-v1.sch]
2014-07-31 Updated regulator design sheet to use smaller inductors
    [regulator-design-sheet.xlsx]
2014-07-31 Finished schematic & placement for the prototype
    [MultiSpork-v1.brd, MultiSpork-v1.sch]
2014-07-31 Shrank the board from 3x4 to 3x3.4
    [MultiSpork-v1.brd]
2014-08-02 -- Updated MAX11300 footprint with rounded pads to account for minimum clearances at the corners -- Added a switch to turn the regulators on and off -- Routed USB -- Routed SPI busses -- Routed analo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
    [MultiSpork-v1.brd, MultiSpork-v1.sch]
2014-08-03 Finished routing
    [MultiSpork-v1.brd, MultiSpork-v1.sch]
2014-08-13 Added a system description document
    [MultiSpork-v1.brd]
2014-08-20 -- Updated system description -- Added case mockup files -- Current routed picture
    [mockup-center.FCStd, mockup-center.dxf, mockup-top.FCStd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]
2014-08-24 More work on the system description
    [MultiSpork-v1.brd]

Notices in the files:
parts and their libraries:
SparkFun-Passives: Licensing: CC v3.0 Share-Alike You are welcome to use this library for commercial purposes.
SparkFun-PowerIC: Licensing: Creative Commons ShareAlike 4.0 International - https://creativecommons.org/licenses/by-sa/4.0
